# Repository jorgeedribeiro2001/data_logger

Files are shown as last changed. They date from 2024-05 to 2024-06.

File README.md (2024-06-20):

# Data Logger Project

## Overview
This repository contains the implementation of a data logger project designed for real-time and remote data acquisition during the shipment of products. The project includes scripts for data processing, device software, and a web interface for data visualization and control.

## Repository Structure

- **Back-End Scripts**: Scripts for data processing and storage.
- **Device Software (Microcontroller)**: Code for the microcontroller used in the data logging device.
- **Django Web-Framework**: Web application framework for interfacing with the data logger.
- **Tests and Results**: Testing scripts and result logs.
- **PCB Project**: KiCad Project of the PCB for the prototype.

## Description of the Implemented Solution

The data logger system uses the ESP32-E Firebeetle 2 microcontroller as the main unit. It works with several sensors to meet the project's requirements:

- **Vibration and Impact Monitoring**: Uses the IAM-20680 accelerometer and gyroscope.
- **Environmental Monitoring**: Uses the BME680 sensor to measure temperature, humidity, and pressure. Both sensors communicate with the microcontroller using the I2C protocol.
- **Data Storage**: Uses a PMod microSD reader module, which communicates via the SPI protocol, for local data storage.
- **Mobile Communication and GPS**: Uses the Ai-Thinker A9G module for mobile network communication and GPS tracking, interfacing via the UART protocol.

Data is sent using the MQTT protocol. Back-end scripts receive this data, convert it to JSON format, and send it to the Django web framework using HTTP Post requests.

##### Django Web Platform

The Django framework manages the data and web platform, providing features such as:

- **Data Storage**: Uses an SQLite database to store user information, trip details, configurations, and data file paths.
- **Interactive Visualization**: Uses JavaScript libraries like Highcharts for graphs and Leaflet for maps to show dynamic data on the trip monitoring page.

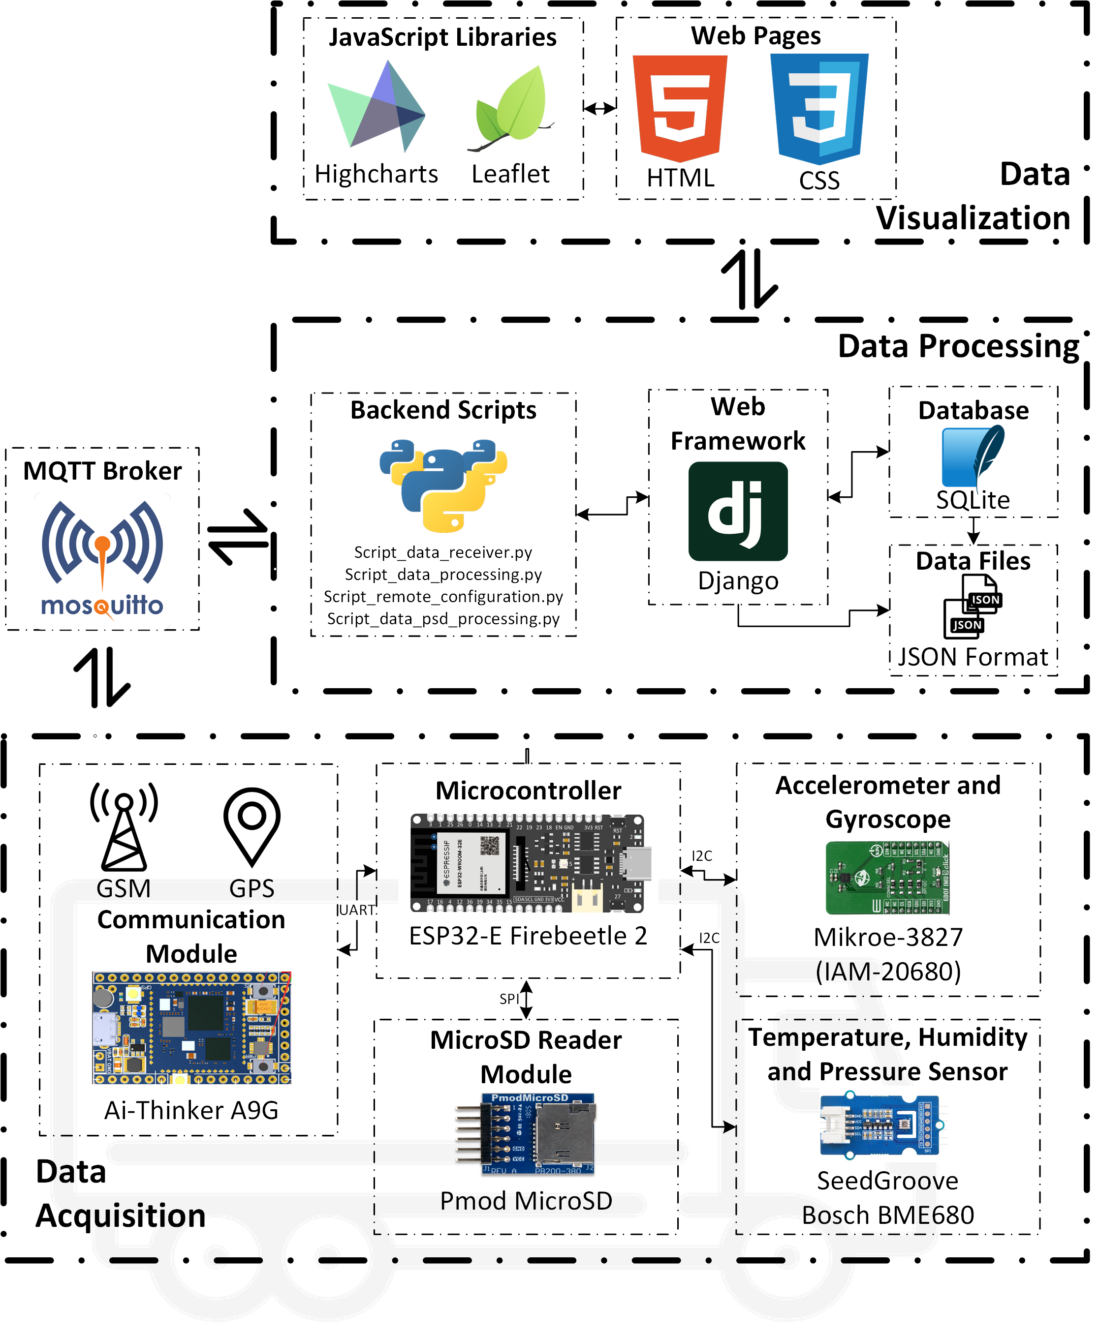
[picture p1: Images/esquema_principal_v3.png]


## Data Acquisition
A prototype was made with a PCB (KiCad Project), as shown in the next picture. This solution has one I2C connector with a Groove connector for the BME680 sensor. Two more I2C connectors are used, each with a TE Connectivity 1744418-4 connector with a 2.5mm pitch. Two SPI connectors have been added. One is for the microSD module, while the other is for the CS pin linked to GPIO 35 (A3) of the ESP32. The latter connector uses the TE Connectivity 1744418-6 with a 2.5mm pitch. This lets you add or try out other sensors. The design also has extra pins for GND, 3V3, and VCC, as well as two ESP32 serial port pins and extra free GPIOs, all marked on the PCB.

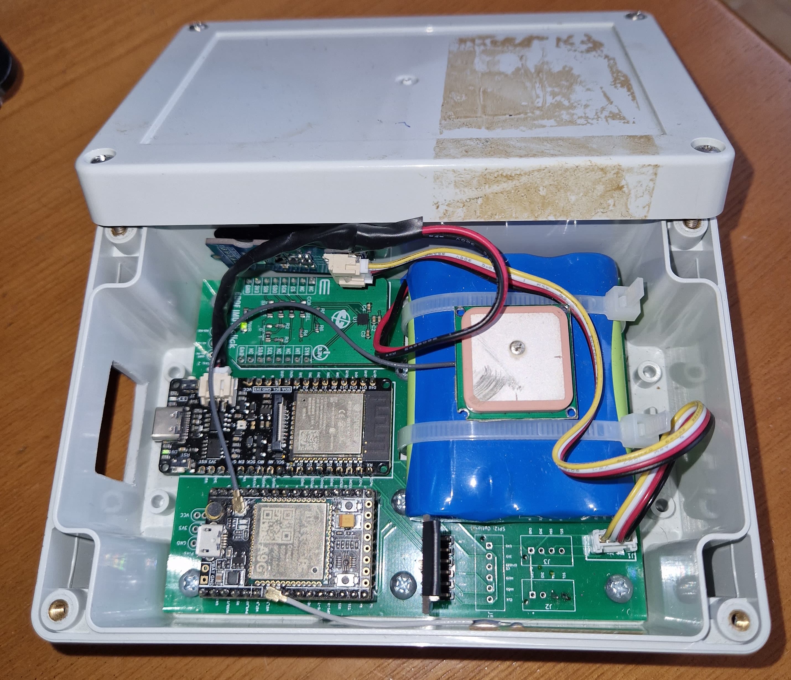
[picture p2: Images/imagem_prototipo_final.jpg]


### Microcontroller Program

The microcontroller program is developed using the ESP32 microcontroller and various sensors to monitor parameters such as temperature, humidity, pressure, impacts, vibration, and location. The code is structured into tasks that handle sensor readings, data storage, and communication with the web platform via MQTT.

### Key Components:
- **ESP32 Microcontroller**: Handles sensor integration and data processing.
- **Sensors**: Include BME680 for environmental data, IMU for motion data, and the Ai-Thinker A9G for location tracking and communication.
- **SD Card**: Certain SD cards are occasionally unrecognised by the device. To ascertain the functionality of an SD card, connect the device to a computer and open a serial port. During the initialisation process, the system will indicate whether the SD card is recognisable. If the card is recognised, the available memory will be displayed. ***It is crucial to format the SD card using the FAT32 file system to ensure proper operation.*** Among the tested SD cards, the Kingston CANVAS Select Plus models with capacities of 32GB and 64GB (class 10) have proven to be reliable.

- **SIM Card**: The device is configured to utilise a SIM plan card for communication via a 2G network to access the internet. The SIM operator employed in this instance is Vodafone Portugal, with the Access Point Name (APN) specified as `net2.vodafone.pt`.
   
   ***It is crucial to note that if a different SIM operator is used, it is necessary to modify the APN configuration within the hardware programme to match the new operator's APN. Furthermore, it is imperative to disable the PIN on the SIM card, as the device lacks the capability to handle PIN entry.*** This functionality must be implemented to avoid potential security vulnerabilities.

### Running the Microcontroller Program:
1. **Set Up the Development Environment**:
   - Install the necessary tools and libraries for ESP32 development.
   - Use the Arduino IDE or PlatformIO for code uploading.

2. **Upload the Code**:
   - Connect the ESP32 to your computer.
   - Compile and upload the code from the `microcontroller` directory.

For initial configurations, the device is pre-configured with specific settings, such as a unique identifier, the initial MQTT address and port, and the APN for network connectivity. This can be encounter on the PogV8.ino file.

hardware_configs

If you do not wish to use the remote configuration feature, you can manually define each configuration below in the `Definitions of Global Variables of the Program` section. To do this, you will need to set the `remote_configuration` variable to `false`. 

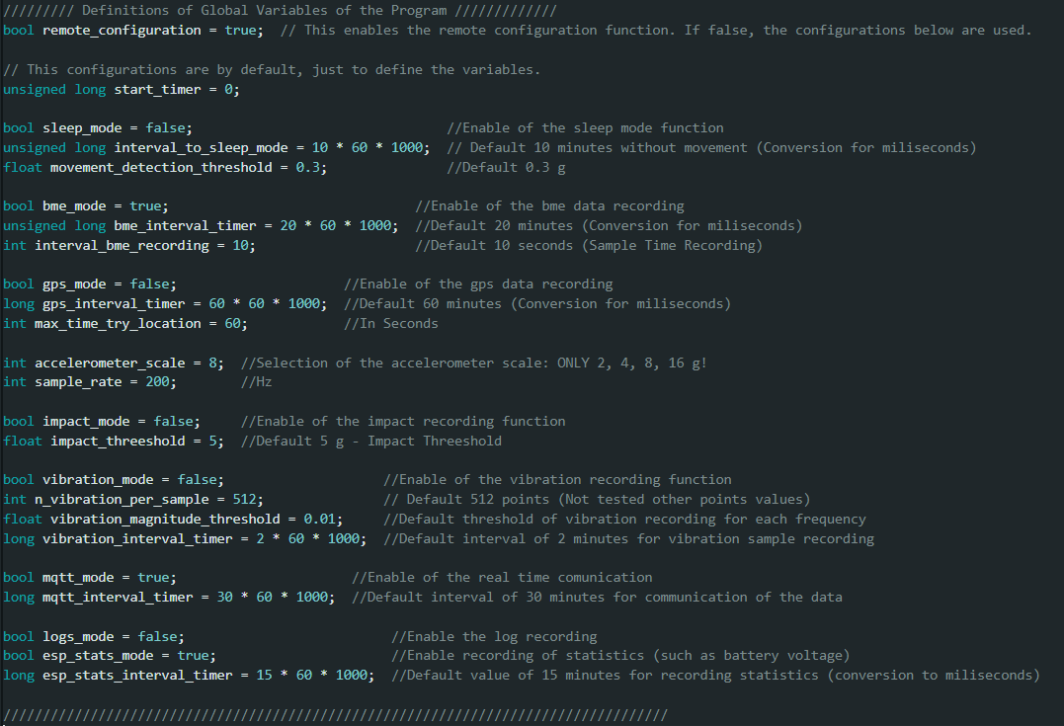
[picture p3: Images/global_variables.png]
hardware_configs2


In the case of remote configuration, if a configuration file is present, the system variables are set according to the specifications outlined in the JSON document created in the "Create Trip" webpage. If the internal memory does not contain a configuration file, the A9G module is activated and configured. This module subscribes to the "config" topic on the MQTT broker and awaits the receipt of the JSON file for up to 60 seconds. During this interval, the embedded LED on the microcontroller is programmed to blink at 500 ms intervals. The user must access the Devices Manager webpage and then press the button "Send Configuration."
Upon receipt of a file, the device proceeds to process it and verify whether the JSON file’s device ID matches the ID coded into the device. Each device ID is unique. If the IDs match, the device sets all global variables and copies the JSON file to the internal memory. Once the configuration is complete, the LED remains illuminated for three seconds before turning off. This signifies the setup process is finished and the system is ready for operation.

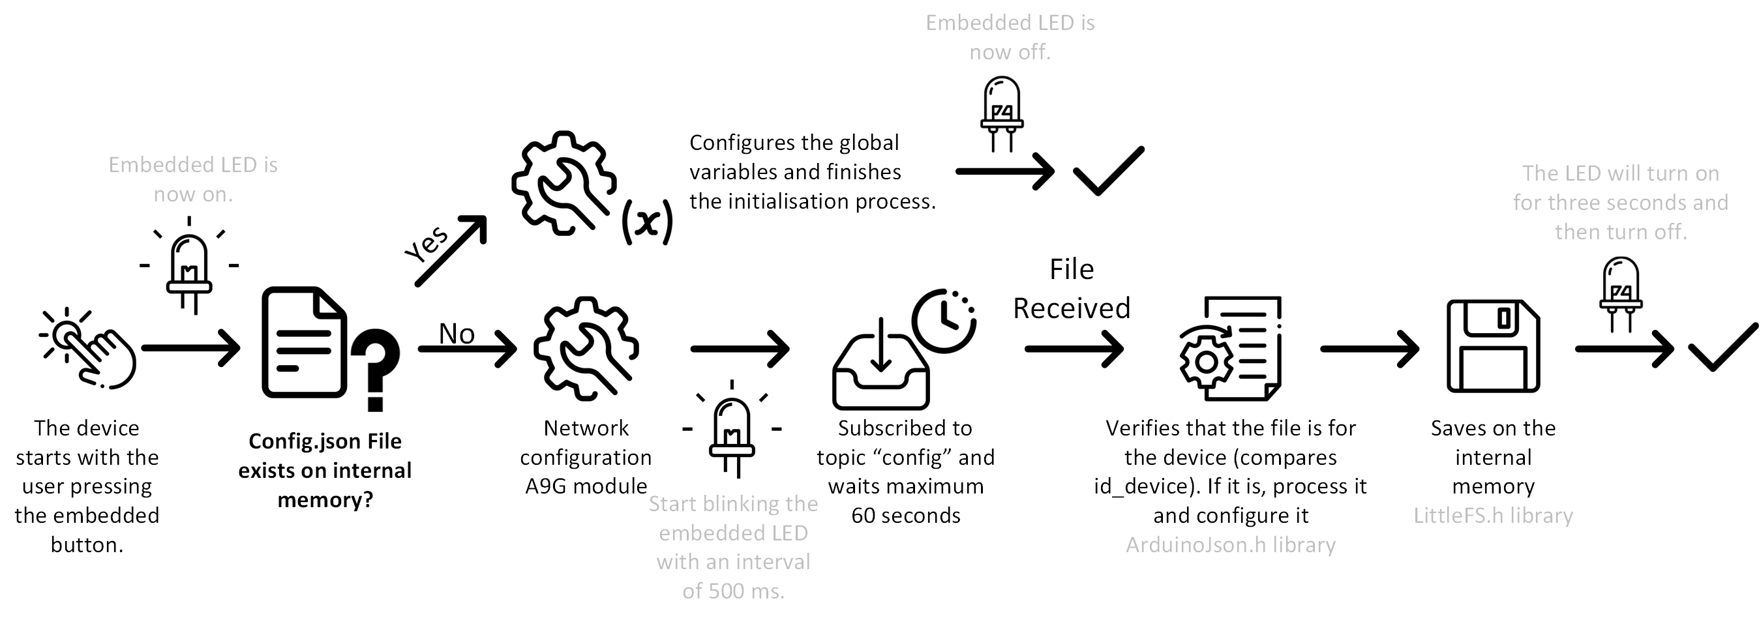
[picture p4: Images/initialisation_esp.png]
remote_config


The end mode, represented in Figure 4.13, is initiated when the user presses the embedded button on the microcontroller for a period of three seconds, thereby initiating the procedure and activating the embedded LED.

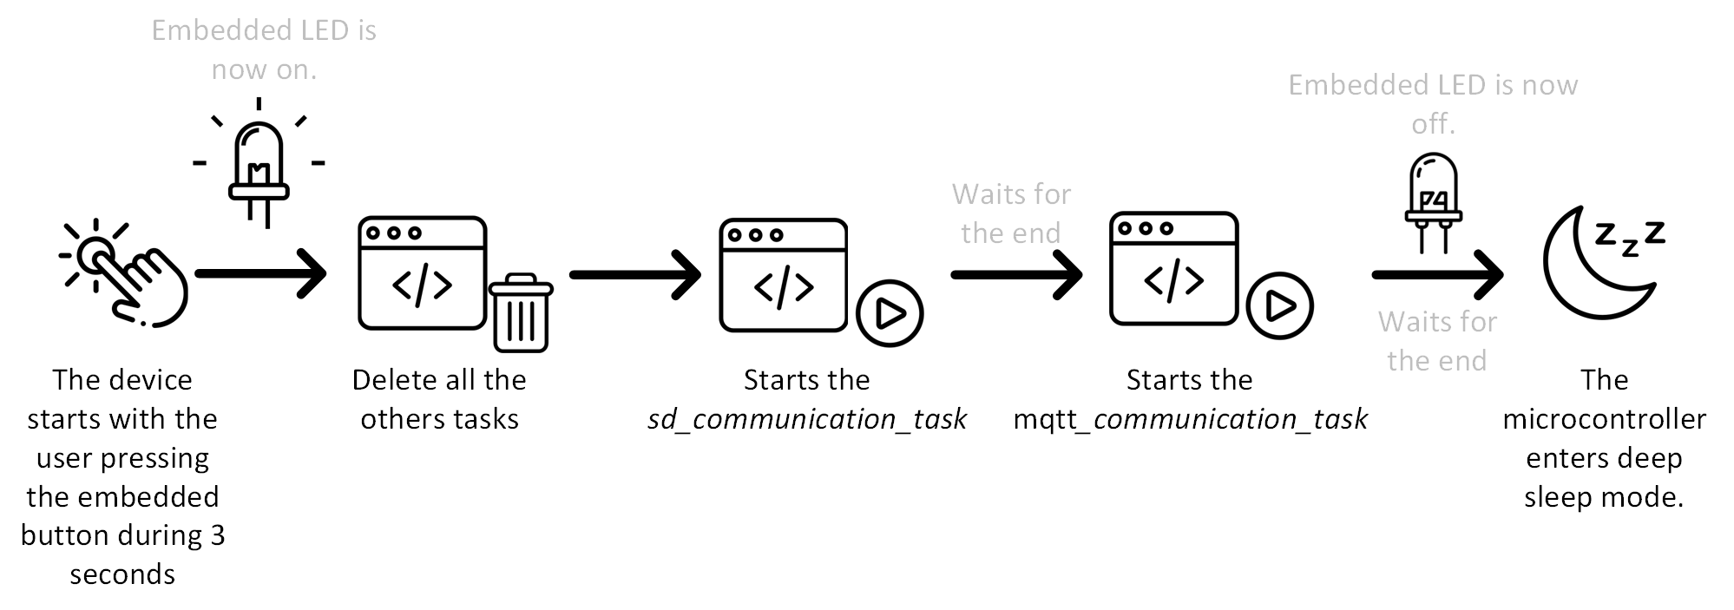
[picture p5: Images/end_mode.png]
end_mode


## Data Processing and Visualization

The data processing and visualization for the data logger system is managed through a series of scripts and a Django-based web platform. The system architecture and the functions of each script are described below.

### System Architecture

1. **Data Acquisition**:
   - The data logger devices collect data on temperature, humidity, pressure, impacts, vibration, and location.
   - This data is transmitted to the MQTT Broker (Mosquitto) using the MQTT protocol.

2. **Data Processing**:
   - **Script Data Receiver**: Subscribes to the MQTT topics to receive data from the data loggers.
   - **Script Data Processing**: Processes the raw data, converts it into JSON format, and prepares it for storage and visualization.
   - **Script Remote Configuration**: Publishes configuration settings to the data loggers.

3. **Data Storage and Management**:
   - The processed data is stored in an SQLite database, which keeps information about users, trips, trip configurations, and data file paths.
   - Additional processing by **Script Data PSD Processing** converts the raw data for FFT segments into Power Spectral Density (PSD) format for further analysis in the web platform.

4. **Web Framework (Django)**:
   - **Views.py**: Handles HTTP requests and returns responses to the client. It interacts with the models and templates to fetch and display data.
   - **Models.py**: Defines the database schema and interacts with the SQLite database to retrieve and store data.
   - **Urls.py**: Maps URLs to the corresponding views, enabling navigation within the web application.
   - **Templates**: HTML files that render the data into user-friendly web pages.

5. **Visualization**:
   - The web platform uses JavaScript libraries such as Highcharts and Leaflet for interactive data visualization.
   - **Highcharts**: Generates interactive graphs to display real-time and historical data on environmental conditions and impacts.
   - **Leaflet**: Provides map visualizations with recorded GPS points for tracking the location of shipments.

### Process Flow

- Data is continuously collected by the data loggers and transmitted via MQTT.
- The **Script Data Receiver** listens for incoming data and passes it to the **Script Data Processing**.
- Processed data is stored in the SQLite database and can be accessed through the Django web platform.
- Users can interact with the platform to configure devices, monitor ongoing trips, and visualize data through dynamic graphs and maps.

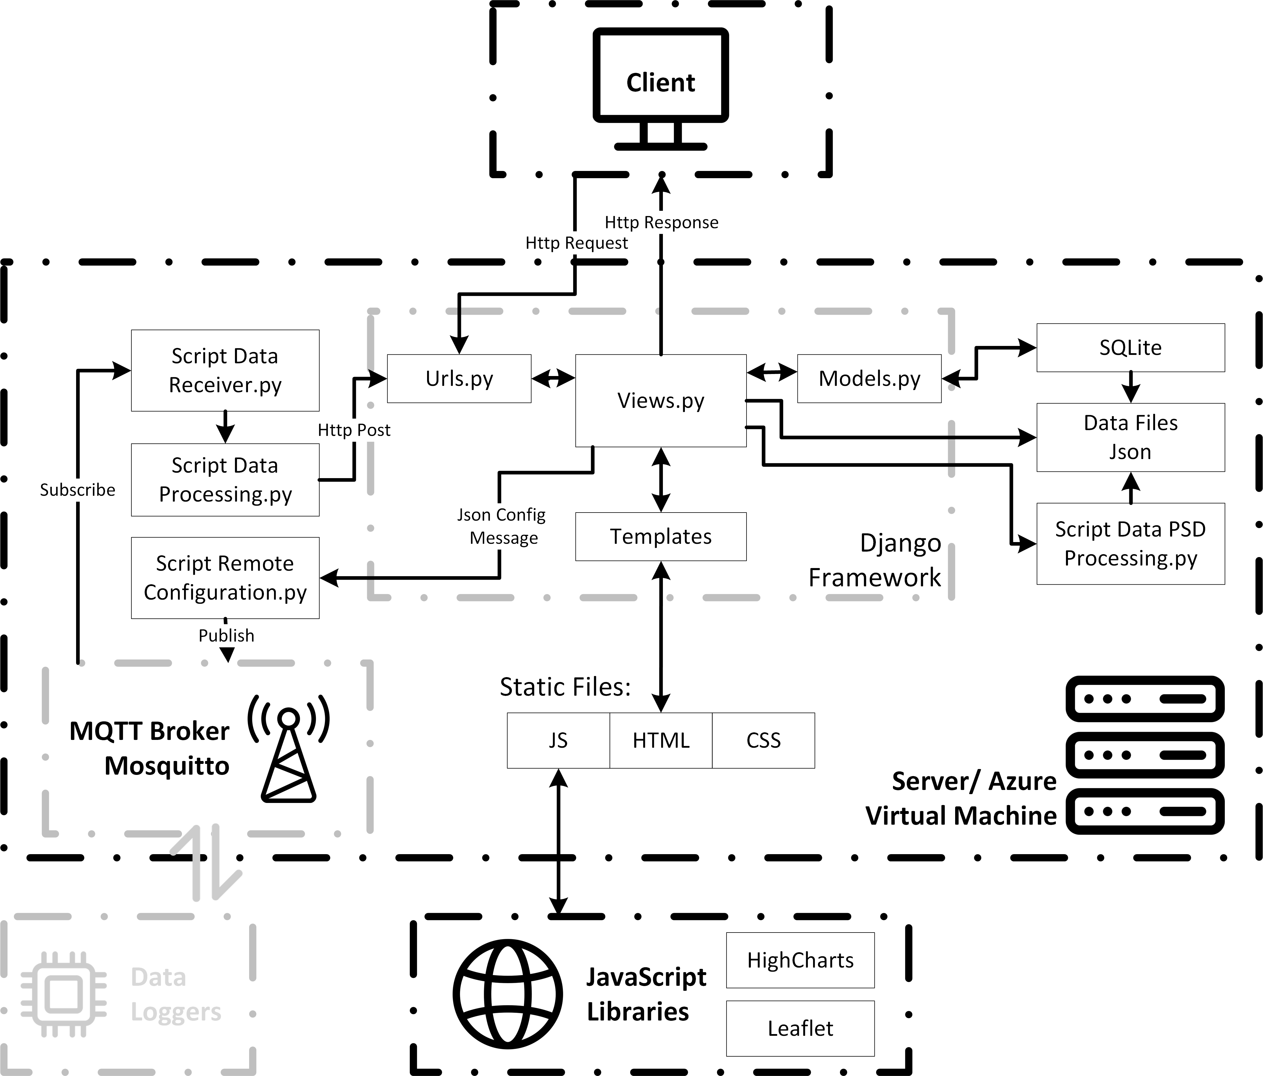
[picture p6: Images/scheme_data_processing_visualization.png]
Platform Diagram


### Running the Server

When setting up the server, three key considerations must be addressed:

- **MQTT Server Configuration**: Although it is possible to use an external MQTT server, such as broker.hivemq.com or broker.emqx.io, it is advisable to install and configure Eclipse Mosquitto on the server to ensure greater system reliability. ***Additionally, Port 1883 should be opened for public access***.

- **Script Data Receiver**: Ensure that the Script Data Receiver (Python Script) is running continuously. This script is designed to operate without interruption and includes error-handling mechanisms to facilitate automatic rebooting. ***It is important to configure the MQTT address and port at the beginning of the program.***

- **Django Web Framework Configuration**: Properly configure the Django web framework. Detailed instructions for configuring Django will be provided in the subsequent section.

#### Running the Django Web-Framework

1. **Clone the Repository**:
   ```bash
   git clone https://github.com/jorgeedribeiro2001/data_logger_project.git
   cd data_logger_project
   ```

2. **Install Dependencies**:
   - For Python components, use the requirements file:
     ```bash
     pip install -r requirements.txt
     ```

3. **Run the Django Application**:
   - Navigate to the Django project directory:
     ```bash
     cd django_project
     ```
   - Apply migrations:
     ```bash
     python manage.py migrate
     ```
   - Create a superuser to access the admin interface:
     ```bash
     python manage.py createsuperuser
     ```
   - Start the development server:
     ```bash
     python manage.py runserver
     ```
   - Access the application at `http://127.0.0.1:8000/`.

To run the Django application over the internet, ensure you have a public IP address and an available port.
It is notable that the platform was not developed for public porposes and not went with any security concerns. Follow these steps to run the application:

1. **Open the Server to External Access**:
   Run the Django development server with the following command to make it accessible over the internet:
   ```bash
   python manage.py runserver 0.0.0.0:8000
   ```

2. **Public IP and Port**:
   - Ensure your server's firewall allows traffic on the specified port (e.g., 8000).
   - Configure your router to forward incoming traffic on this port to your server if running behind a NAT.

3. **Security Considerations**:
   - This platform was developed for demonstration purposes and internal use only.
   - It lacks security features necessary for a public-facing application.
   - If you intend to make this application accessible over the internet, implement proper security measures such as HTTPS, firewalls, authentication, and regular security audits.

4. **Deployment Recommendations**:
   - For production deployment, use a robust web server like Nginx or Apache as a reverse proxy.
   - Consider using a WSGI server like Gunicorn or uWSGI to serve the Django application.
   - Set up SSL/TLS certificates for secure HTTPS connections.

### Graphical Interface

The graphical interface of the data logger system includes several user-accessible pages designed as adaptable templates. These templates ensure that the HTML pages dynamically respond to user requests. For instance, when a user monitors a trip, the page's structure and elements adjust automatically to display the specific trip data selected by the user. Below is a visual representation of the hierarchical structure of these pages:

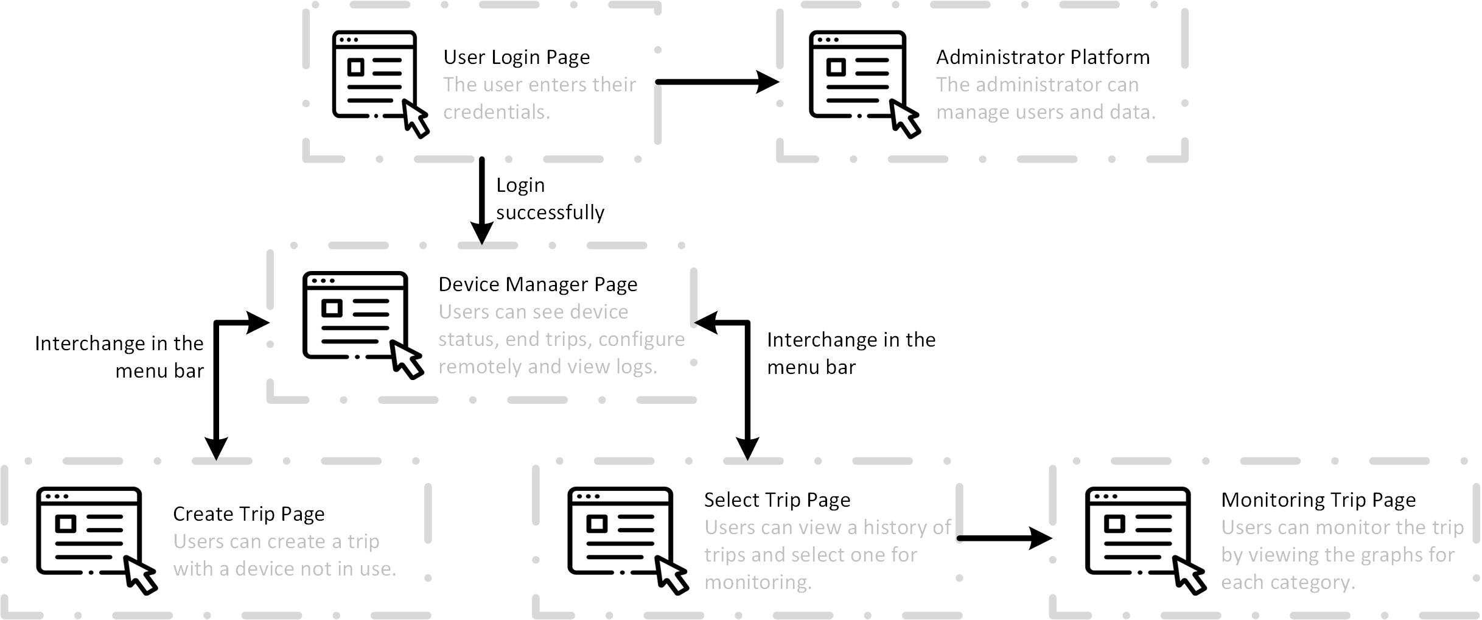
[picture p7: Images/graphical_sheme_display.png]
Web Pages Interaction Diagram

*Figure: Web Pages Interaction Diagram*

#### Page Descriptions

##### User Login Page
The user login page is the primary access point for users. It features a straightforward interface where users can enter their credentials. Upon successful login, users are redirected to the appropriate dashboard. Administrators can also access the administrative platform from this page.

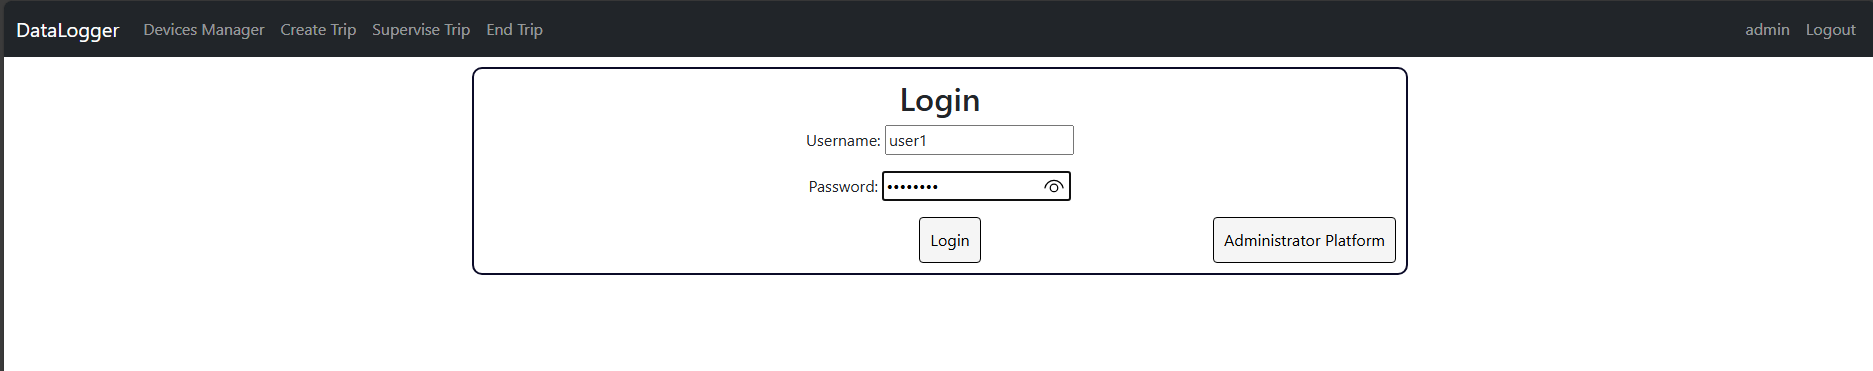
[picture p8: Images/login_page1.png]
User Login Layout

*Figure: User Login Layout*

##### Administrator Platform
This platform is accessible only to administrators. It provides comprehensive data access and user management capabilities, allowing administrators to manage users, modify values in the SQLite database, and oversee data collected by the devices.

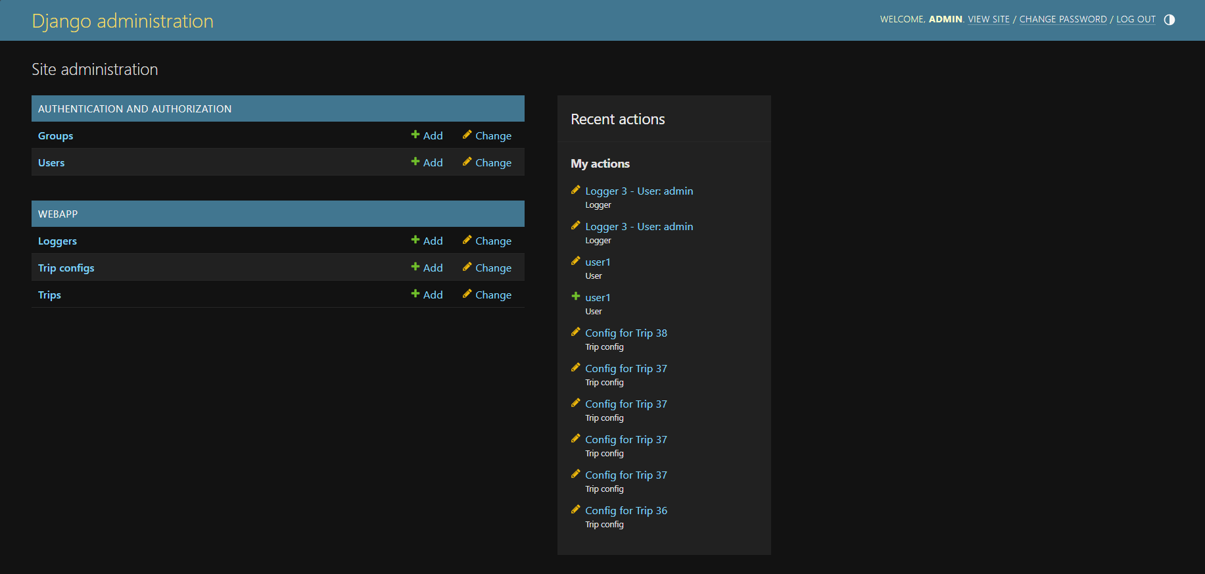
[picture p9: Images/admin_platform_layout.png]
Administrator Platform Layout

*Figure: Administrator Platform Layout*

##### Device Manager Page
Upon logging in, users are redirected to the Device Manager page. This page can also be accessed via the menu bar. It requires user authentication and displays the devices added by the user. Administrators can view all devices. Users can see device status, end trips, configure devices remotely, and view logs.

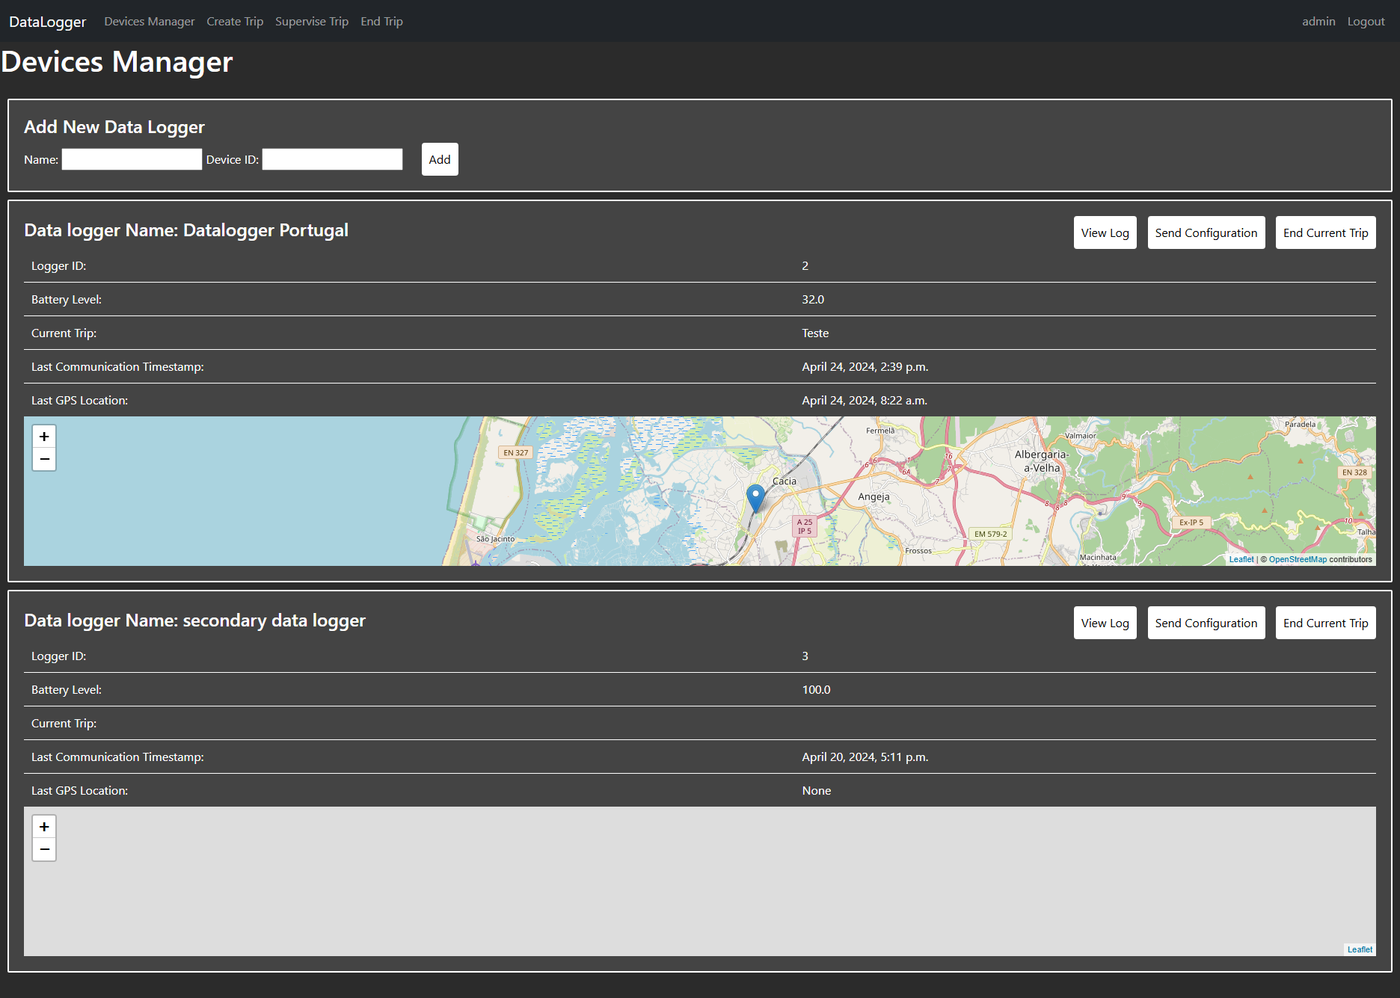
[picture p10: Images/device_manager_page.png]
Device Manager Page Layout

*Figure: Device Manager Page Layout*

##### Create Trip Page
This page allows users to create a new trip and configure the associated device settings. Users can navigate to this page via the menu bar or through a specific link. They can define the trip name, select an available data logger, and set the start date. Configuration parameters can be set, and a JSON file can be generated for saving on the user's computer.

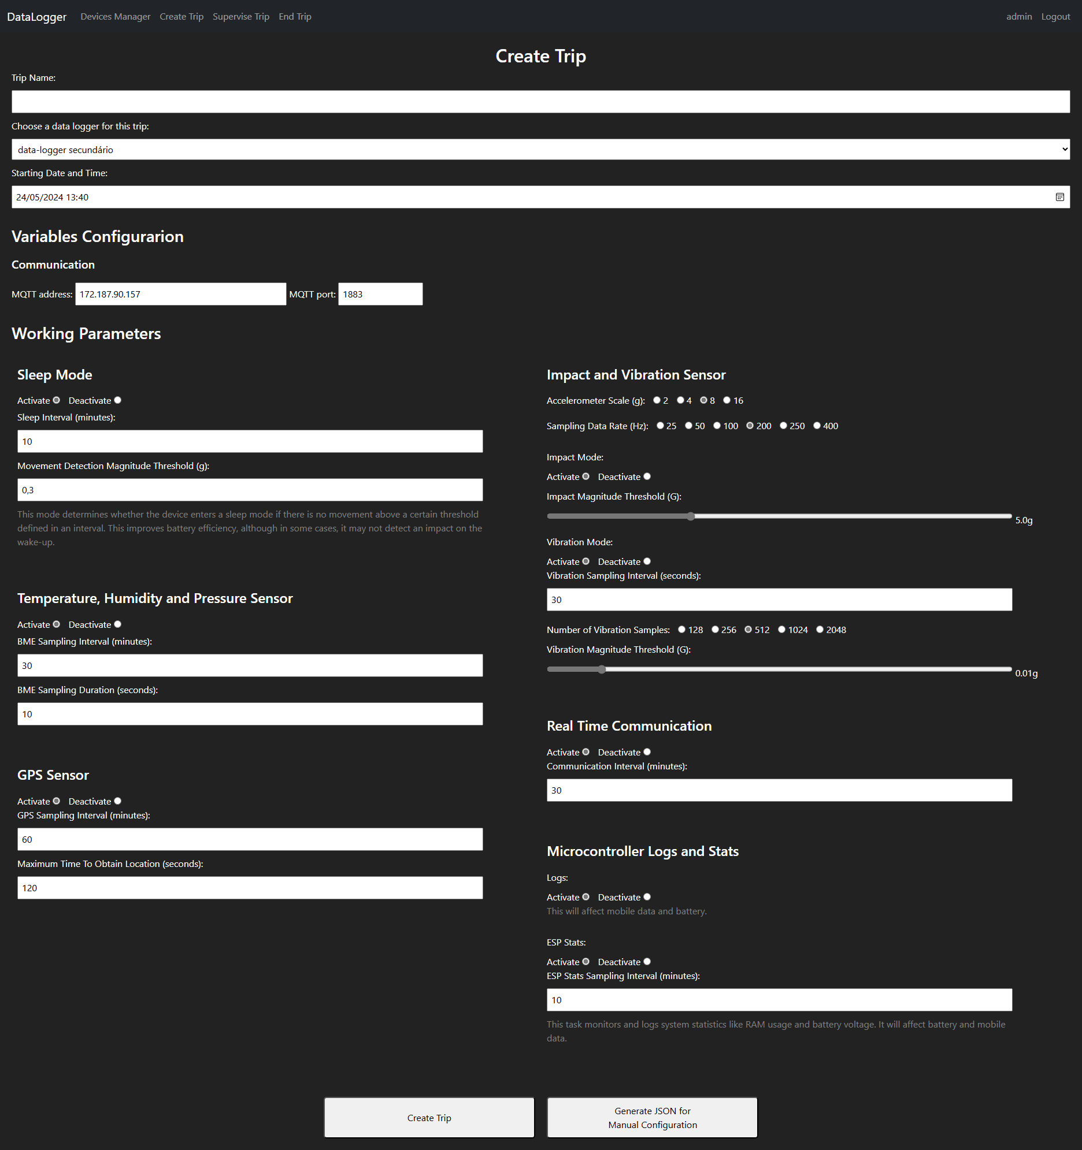
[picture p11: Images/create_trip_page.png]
Create Trip Page Layout

*Figure: Create Trip Page Layout*

##### Select Trip Page
The Select Trip page allows users to view and select from a list of their trips. Users can delete a trip or proceed to monitor it. This page is accessible via the menu bar and requires user authentication.

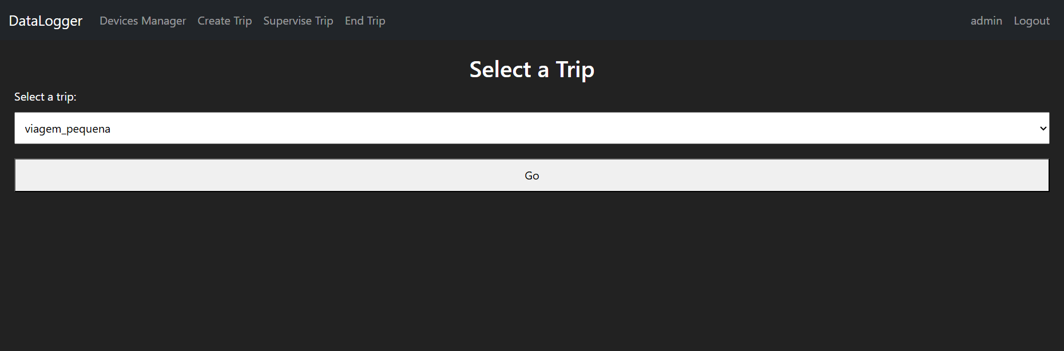
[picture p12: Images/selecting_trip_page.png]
Select Trip Page Layout

*Figure: Select Trip Page Layout*

##### Monitoring Trip Page
This page is crucial for data analysis and visualization. It is divided into sections for general trip details, BME data (temperature, humidity, pressure), IMU data (impact, vibration), and location data. Each section provides detailed analysis and interactive graphs.

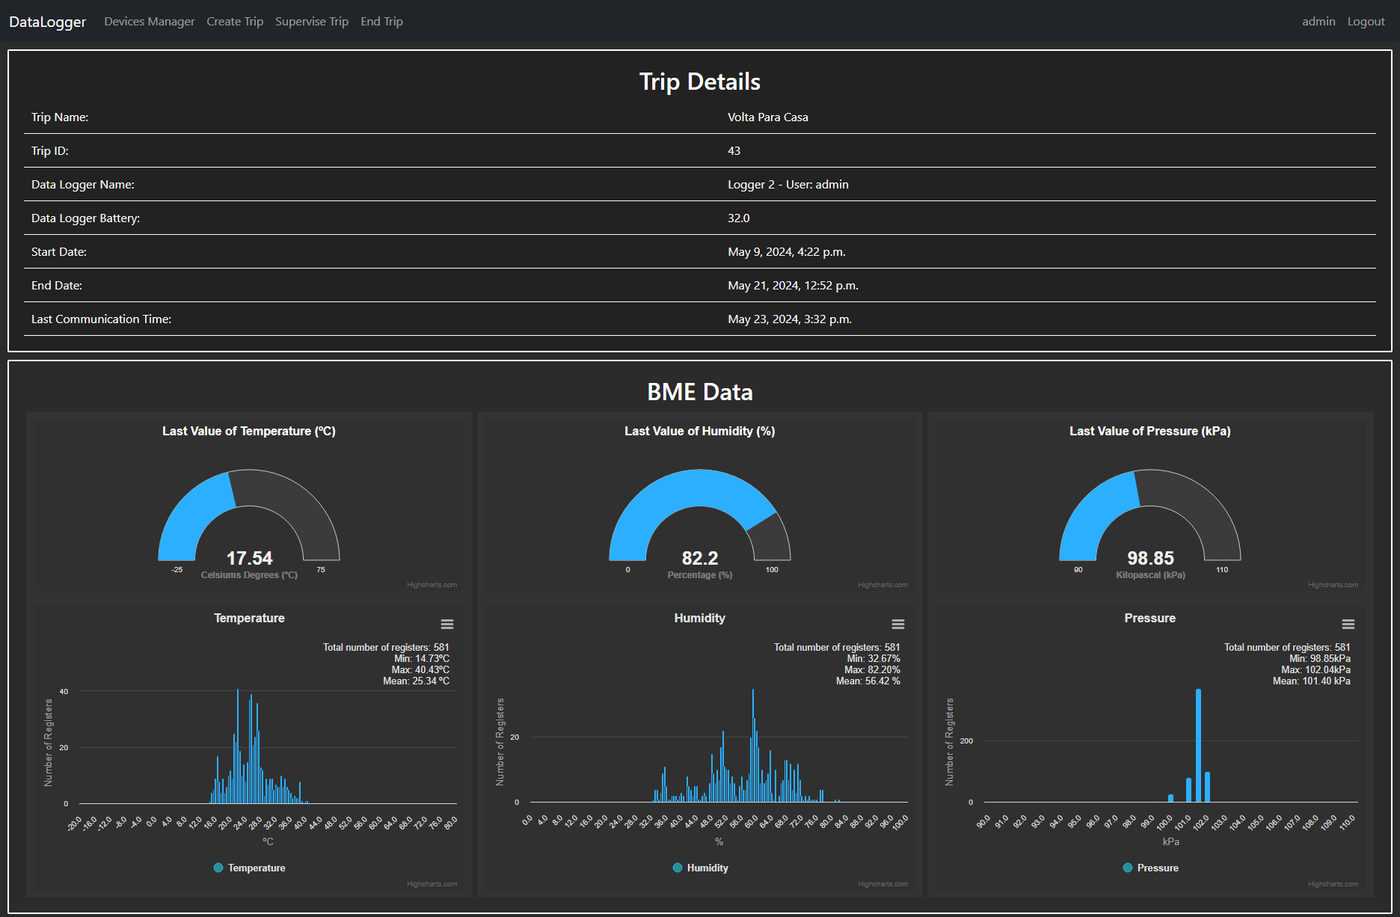
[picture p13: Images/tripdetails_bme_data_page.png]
Monitoring Page: Trip Details and BME Data Sections Layout

*Figure: Monitoring Page: Trip Details and BME Data Sections Layout*

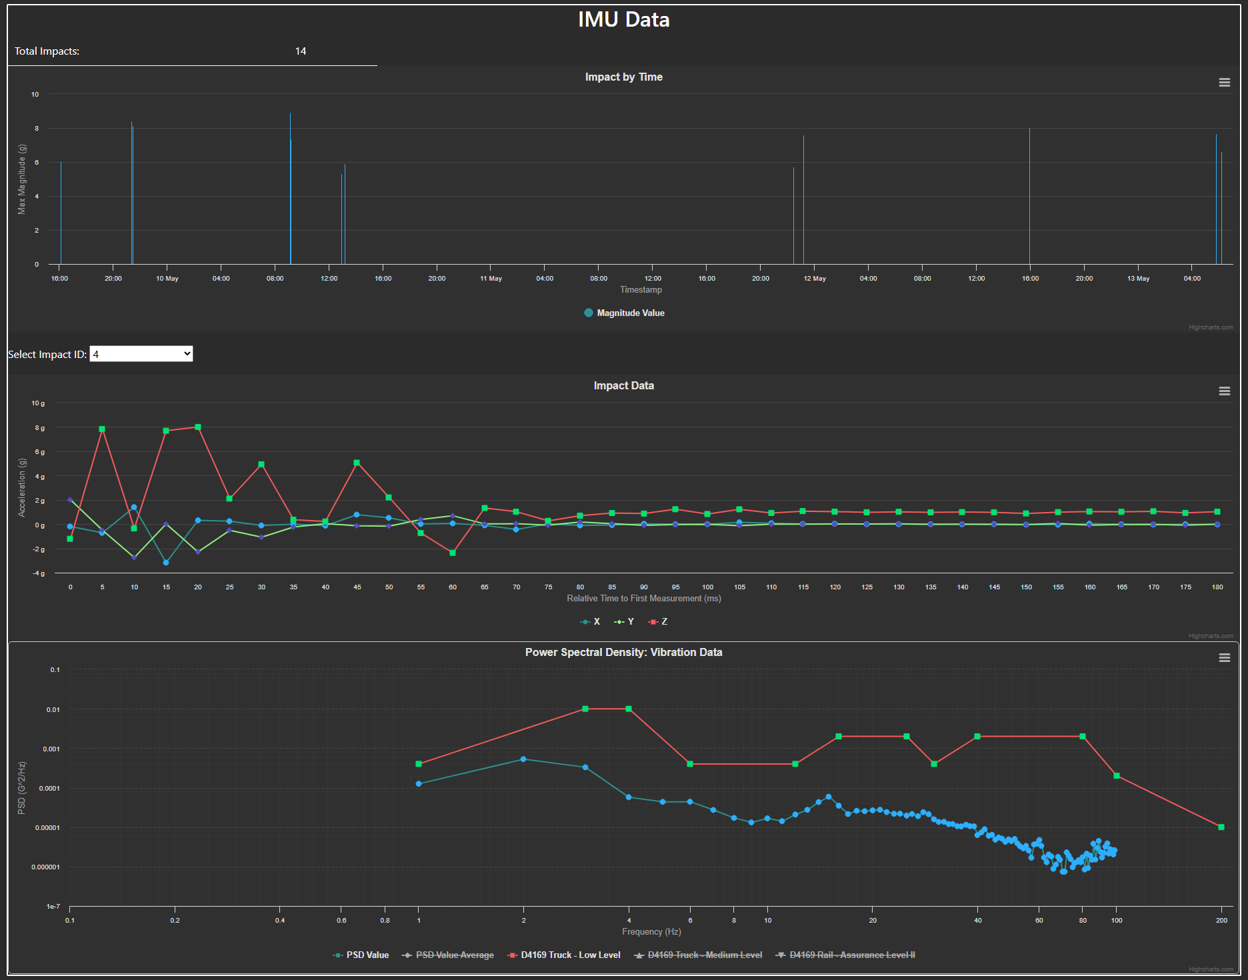
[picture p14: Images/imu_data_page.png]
Monitoring Page: IMU Data Section Layout

*Figure: Monitoring Page: IMU Data Section Layout*

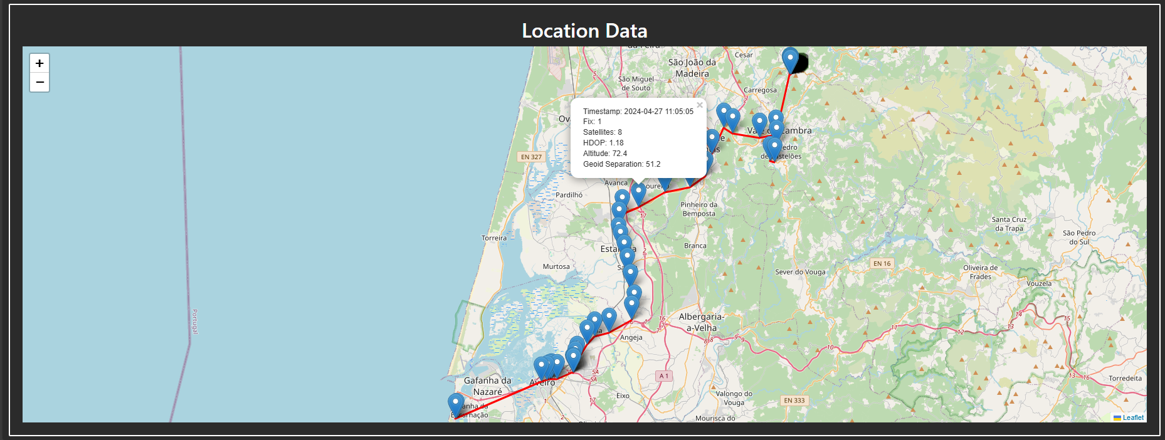
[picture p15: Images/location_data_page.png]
Monitoring Page: Location Section Layout

*Figure: Monitoring Page: Location Section Layout*

#### JavaScript Libraries
The interactive graphs and maps are created using the Highcharts and Leaflet JavaScript libraries. Highcharts is used for generating interactive graphs, while Leaflet is used for creating interactive maps with recorded position points. These tools provide dynamic visualization of the data collected by the data logger devices.

This graphical interface ensures a user-friendly and efficient way to manage devices, create and monitor trips, and visualize data for analysis, making it a vital part of the data logger system.

## Troubleshooting

##### When I turn on the device, the light is always on indefinitely.

This issue may arise due to initialization errors, often related to inaccessible sensors or the communication module's inability to connect to the network for remote configuration or microSD incompatibility. To troubleshoot, follow these steps:

- Verify that all sensor connections are secure.
- Ensure a compatible microSD card is in place.
- Confirm that the SIM card is functioning correctly.
- Check that the MQTT settings are properly configured.
  
To determine the specific cause, connect the device to a computer, open a serial port, and restart the device. This will display initialization information on the serial port. The baud rate should be set to 115200 bps.

##### The remote configuration does not work (the light keeps blinking after I click the Send Configuration button on the web platform).

This issue may be attributed to improper configuration of the MQTT server settings. Ensure that the device is configured with the correct MQTT broker address and port. Additionally, verify that the appropriate settings have been entered on the Create Trip webpage.

##### Despite the device being deployed in the field, the web platform is not receiving or displaying updated data.

Verify if the script data receiver is running with the correct MQTT configurations. Additionally, check if the issue is isolated to a single device or affects multiple devices. Examine the last communication timestamp of the device and ensure that the trip configurations have the communication interval set correctly. If all these aspects are in order, contact the repository owner for further assistance. Remember that the device communication might be skipped during the programmed interval but will resume in the subsequent interval.

## License
This project is licensed under the GNU General Public License v3.0.

## Contact
For any queries, contact the repository owner on LinkedIn page: https://www.linkedin.com/in/jorgeedribeiro/ 

---

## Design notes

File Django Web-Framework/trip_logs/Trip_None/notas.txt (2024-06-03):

DHl, rastreablilidade, transportadoras teses relacionadas 

dano no produto 

Henrique apresentação efacec 18 segunda 16h15

Transformada de Forier

rever 10 a 20 artigos e fazer uma pagina de resumo (analise do problema, soluçao proposta, metodo de analise de resultados, conclusoes) tiirar partes fundamentais para o projeto (sumo)

algoritmo de processamento de dados para vibrações (procurar artigos cientificos)

jason 

17:10 06/12/2023
artigos para verificar a antena de gps e erro de posição
dois cores processadores 
spyes dual cores, core posso ter varios processos
guardar na ram array[0] a [10] tem x valores de gps outros tem outra cena
processos independentes  
de ram

array[] com os parametros 
fluxograma de comandos AT

relação entre tempo e frequencia de vibração
um mes de performance em quanto nos testes
histograma de frequencia
retirar frequencia amostragem durante x tempo

francisco
teste de queue

try catch for log

te connectivity
174417-4 2.5mm

meter modulo de cartao sd
substituir por conector o mesmo com 6 pinos
tdl100 e 140 fazer comparação

SAVER 3X90

Apos acordar tem de registar algum valor a dozer que sofreu impacto ou que

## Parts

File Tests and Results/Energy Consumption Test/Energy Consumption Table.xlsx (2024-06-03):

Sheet: Individual Tests
Individual Tests
Sensor |  |  | Bosch BME680 |  | IAM-20680 | A9G |  |  |  | MicroSD |  | ESP32
Test |  |  | Data Recording Cycle | Sleeping Mode | Continuous monitoring of accelerometer values | Module Initialization (Reseting) | GPS Data Recording | MQTT data transmission | Sleep Mode | Data Writting | Sleep Mode | Tasks Manager Running | Sleep Mode
Test Description |  |  | A cycle that simulates the normal data recording procedure: switch on, record for 10 seconds (temperature, humidity and pressure) and then switch to the low power mode. | Consumption during 2 minutes | Consumption during 2 minutes | Start from normal mode and perform a reset to wake up the module and to configure it. | A cycle that simulates the normal data acquisition procedure: Switch on the GPS, wait for a maximum of 60 seconds to fix the satellite and, if successful, store the coordinates and then switch off the GPS. | Initial configuration of the network and then transfer of data from the microSD card | Consumption during a standby period | A cycle that simulates the process of transferring data from the RAM to the MicroSD. | Consumption during a standby period | Consumption measured on the microcontroller only when it is running on normal mode | Consumption measured on the microcontroller only when it is running on sleeping mode
Parameters |  |  | Mode: Forced Mode Over-Sampling 8x | Mode: Sleep-Mode | ODR 250 Hz Over-Sampling 8x | AT Command (AT+RST=1) | 60 Seconds Maximum Time to obtain Location | 1 minute duration. 15 setences per message. | 1 minute duration. | Testing using the Kingston SDCS2/32GB MicroSD Data Writting of 3 registers of Impacts Data and 5 registers of BME Data SPI frequency : 1MHz | 1 minute duration. | CPU Frequency: 160 MHz | CPU Frequency: 160 MHz
Results (1st Test) | Average Bus Voltage (V) |  | 3.25 | 3.26 | 3.24 | 4.80 | 4.77 | 4.71 | 4.81 | 3.30 | 3.26 | 3.90 | 3.92
 | Current Consumption (mA) | Min. Value | -0.01 | 0.00 | 5.30 | 11.00 | 12.50 | 13.40 | 2.00 | 0.40 | 0.30 | 31.90 | 1.50
 |  | Max. Value | 14.00 | 0.80 | 6.70 | 400.00 | 126.70 | 400.00 | 83.60 | 62.90 | 0.40 | 58.30 | 1.70
 |  | Avg. Value | 2.60 | 0.43 | 5.64 | 39.45 | 52.82 | 128.41 | 4.00 | 18.72 | 0.33 | 48.45 | 1.60
 | Shunt Voltage (mV) | Min. Value | -0.01 | 0.00 | 0.53 | 1.09 | 1.25 | 1.34 | 0.20 | 0.05 | 0.02 | 3.31 | 0.15
 |  | Max. Value | 1.63 | 0.04 | 0.63 | 40.00 | 12.52 | 40.00 | 80.90 | 5.82 | 0.04 | 5.77 | 0.17
 |  | Avg. Value | 0.23 | 0.00 | 0.56 | 4.46 | 5.29 | 12.32 | 0.40 | 1.80 | 0.03 | 4.86 | 0.16
 | Power Consumption (mW) | Min. Value | 0.00 | 0.00 | 18.00 | 52.00 | 61.00 | 64.00 | 10.00 | 2.00 | 2.00 | 128.00 | 7.00
 |  | Max. Value | 46.00 | 2.00 | 21.00 | 1924.00 | 596.00 | 1927.00 | 403.00 | 200.00 | 2.00 | 228.00 | 7.00
 |  | Avg. Value | 8.44 | 1.38 | 18.36 | 177.91 | 251.15 | 587.63 | 19.15 | 59.32 | 2.00 | 186.33 | 7.00
 | Total Energy Con. (mWh) |  | 0.037980 | 0.023110 | 0.613525 | 1.008170 | 4.590470 | 9.826440 | 0.320690 | 0.535530 | 0.033500 | 3.159830 | 0.117440
Results (2st Test) | Average Bus Voltage (V) |  | 3.25 | - | 3.24 | 4.79 | 4.77 | 4.66 | 4.80 | 3.27 | 3.26 | 3.90 | -
 | Current Consumption (mA) | Min. Value | -0.10 | - | 5.30 | 11.10 | 12.60 | 63.80 | 2.00 | 0.50 | 0.20 | 32.50 | -
 |  | Max. Value | 14.80 | - | 6.50 | 400.00 | 118.10 | 400.00 | 75.20 | 63.40 | 0.40 | 55.50 | -
 |  | Avg. Value | 1.87 | - | 5.60 | 37.66 | 48.42 | 170.66 | 4.22 | 18.55 | 0.31 | 48.33 | -
 | Shunt Voltage (mV) | Min. Value | -0.01 | - | 0.54 | 1.11 | 1.26 | 6.48 | 0.20 | 0.04 | 0.02 | 3.23 | -
 |  | Max. Value | 1.66 | - | 0.64 | 40.00 | 11.84 | 40.00 | 7.60 | 6.34 | 0.04 | 5.55 | -
 |  | Avg. Value | 0.20 | - | 0.56 | 4.19 | 4.84 | 16.56 | 0.44 | 1.77 | 0.03 | 4.86 | -
 | Power Consumption (mW) | Min. Value | 0.00 | - | 16.00 | 52.00 | 61.00 | 305.00 | 10.00 | 2.00 | 0.00 | 128.00 | -
 |  | Max. Value | 39.00 | - | 21.00 | 1458.00 | 557.00 | 1912.00 | 398.00 | 185.00 | 2.00 | 216.00 | -
 |  | Avg. Value | 6.03 | - | 18.21 | 165.53 | 231.49 | 794.36 | 20.21 | 60.31 | 2.00 | 186.06 | -
 | Total Energy (mWh) |  | 0.028310 | - | 0.608012 | 0.942610 | 4.192530 | 13.305390 | 0.337970 | 0.604810 | 0.033390 | 3.121690 | -
Results (3st Test) | Average Bus Voltage (V) |  | 3.25 | - | 3.24 | 4.80 | 4.77 | 4.67 | 4.80 | 3.28 | 3.26 | 3.90 | -
 | Current Consumption (mA) | Min. Value | -0.10 | - | 5.30 | 10.90 | 12.50 | 61.20 | 2.00 | 0.30 | 0.20 | 38.00 | -
 |  | Max. Value | 15.70 | - | 6.60 | 400.00 | 115.20 | 400.00 | 81.10 | 63.10 | 0.40 | 55.90 | -
 |  | Avg. Value | 2.45 | - | 5.60 | 42.66 | 48.11 | 167.75 | 3.77 | 17.13 | 0.32 | 48.90 | -
 | Shunt Voltage (mV) | Min. Value | -0.01 | - | 0.54 | 1.09 | 1.25 | 6.13 | 0.20 | 0.04 | 0.02 | 3.31 | -
 |  | Max. Value | 1.21 | - | 0.65 | 40.00 | 11.49 | 40.00 | 8.11 | 4.91 | 0.04 | 5.58 | -
 |  | Avg. Value | 0.22 | - | 0.55 | 4.46 | 4.81 | 16.48 | 0.36 | 1.72 | 0.03 | 4.93 | -
 | Power Consumption (mW) | Min. Value | 0.00 | - | 18.00 | 52.00 | 61.00 | 285.00 | 10.00 | 2.00 | 0.00 | 129.00 | -
 |  | Max. Value | 51.00 | - | 21.00 | 1892.00 | 542.00 | 1914.00 | 382.00 | 200.00 | 2.00 | 218.00 | -
 |  | Avg. Value | 8.29 | - | 18.48 | 176.06 | 228.99 | 780.09 | 16.81 | 55.93 | 1.99 | 190.14 | -
 | Total Energy (mWh) |  | 0.030860 | - | 0.617540 | 0.953620 | 4.115390 | 13.044670 | 0.281060 | 0.501830 | 0.033280 | 3.184830 | -

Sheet: Use Case
Use Case
Start Point
Type | Time | Decimal |  | Total Time | Percentage
Transport | 5h10m | 5.17 | Theorical Transport: | 78.94 | 88.09%
Storage | 0h00m | 0 | Taking into account a rest period of 9 hours in a 24-hour period of transport
Transport | 20h51m | 20.85
Storage | 0h04m | 0.07 | Resting: | 29.60 | 33.03%
Transport | 34h42m | 37.7 | Storage: | 10.67 | 11.91%
Storage | 10h36m | 10.6 | Real Transport: | 49.34 | 55.06%
Transport | 15h13m | 15.22
End Point
Total: |  | 89.61

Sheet: Consumption per Mode and Hour
Estimated Power Consumption
Action/component | Mode | Active Mode (Real Transport) | Sleeping Mode (Storage + Resting)
 | Mode Usage Percentage: | 55% | 45%
bme | nº cycles | 2 | 1
 | Usage Time per cycle (minutes) | 0.17 | 0.17
 | Percentage Usage (%) | 0.56% | 0.28%
 | Active Power Consumption (mW) | 7.587 | 7.587
 | Sleep Power Consumption (mW) | 1.380 | 1.380
 | Total Energy per hour (mWh) | 1.414 | 1.397
imu | nº cycles | 1 | 1
 | Usage Time per cycle (minutes) | 60.00 | 60.00
 | Percentage Usage (%) | 100.00% | 100.00%
 | Active Power Consumption (mW) | 18.350 | 18.350
 | Sleep Power Consumption (mW) | 0.000 | 0.000
 | Total Energy per hour (mWh) | 18.350 | 18.350
A9G | Module Inicialization
 | nº cycles | 1 | 0
 | Usage Time per cycle (minutes) | 0.33 | 0.33
 | Percentage Usage (%) | 0.56% | 0.00%
 | Active Power Consumption (mW) | 173.167 | 173.167
 | Total Energy per hour (mWh) | 0.962 | 0.000
 | GPS
 | nº cycles | 1 | 0
 | Usage Time per cycle (minutes) | 1.00 | 1.00
 | Percentage Usage (%) | 1.67% | 0.00%
 | Active Power Consumption (mW) | 237.210 | 237.210
 | Total Energy per hour (mWh) | 3.954 | 0.000
 | Data Transmission
 | nº cycles | 1 | 0
 | Usage Time per cycle (minutes) | 5.00 | 5.00
 | Percentage Usage (%) | 8.33% | 0.00%
 | Active Power Consumption (mW) | 720.693 | 720.693
 | Total Energy per hour (mWh) | 60.058 | 0.000
 | Module
 | Usage Time (minutes) | 53.67 | 60.00
 | Percentage Usage (%) | 89.44% | 100.00%
 | Sleep Power Consumption (mWh) | 18.723 | 18.723
 | Total Energy per hour (mWh) | 16.747 | 18.723
Micro-SD | nº cycles | 5 | 1
 | Usage Time per cycle (minutes) | 2.00 | 2.00
 | Percentage Usage (%) | 16.67% | 3.33%
 | Active Power Consumption (mW) | 58.520 | 58.520
 | Sleep Power Consumption (mW) | 1.997 | 1.997
 | Total Energy per hour (mWh) | 11.417 | 3.881
Microcontroller | nº cycles | 1 | 2
 | Usage Time per cycle (minutes) | 60.00 | 5.00
 | Percentage Usage (%) | 100.00% | 16.67%
 | Active Power Consumption (mW) | 187.510 | 187.510
 | Sleep Power Consumption (mW) | 7.000 | 7.000
 | Total Energy per hour (mWh) | 187.510 | 37.085
Total Energy (per hour) (mWh): |  | 300.412 | 79.436
Total Energy (per hour) (mWh): |  | 200.973
Total Energy (per day) (mWh): |  | 4823.351

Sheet: Expected Battery Life
Expected Battery Life
Manufacturer | Nominal Voltage (V) | Capacity (mAh) | Price (€) | Capacity (mWh) | Expected Battery Life (days)
RS Components | 3.7 | 2000 | 22.33 € | 7400 | 1.53
 | 3.7 | 5200 | 23.46 € | 19240 | 3.99
 | 3.7 | 7800 | 30.05 € | 28860 | 5.98
 | 3.7 | 10400 | 36.88 € | 38480 | 7.98
 | 5.0 | 20000 | 27.70 € | 100000 | 20.73

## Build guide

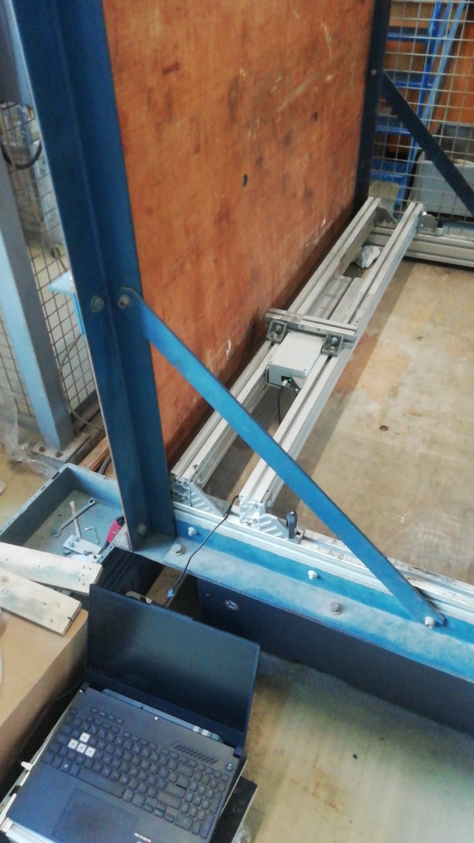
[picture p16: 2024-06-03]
Tests and Results/Vibration Validation Test/Setup Images/IMG-20240514-WA0007.jpg

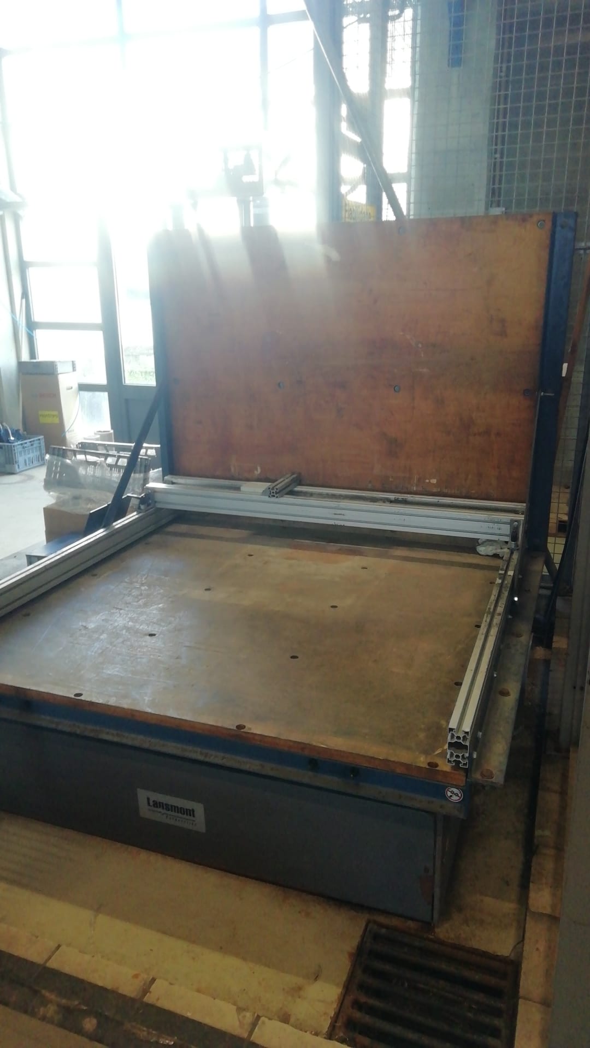
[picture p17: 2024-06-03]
Tests and Results/Vibration Validation Test/Setup Images/IMG-20240514-WA0008.jpg

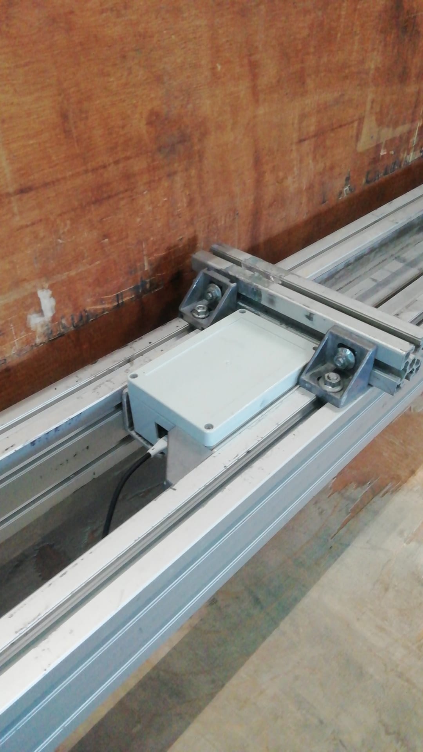
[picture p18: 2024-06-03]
Tests and Results/Vibration Validation Test/Setup Images/IMG-20240514-WA0014.jpg

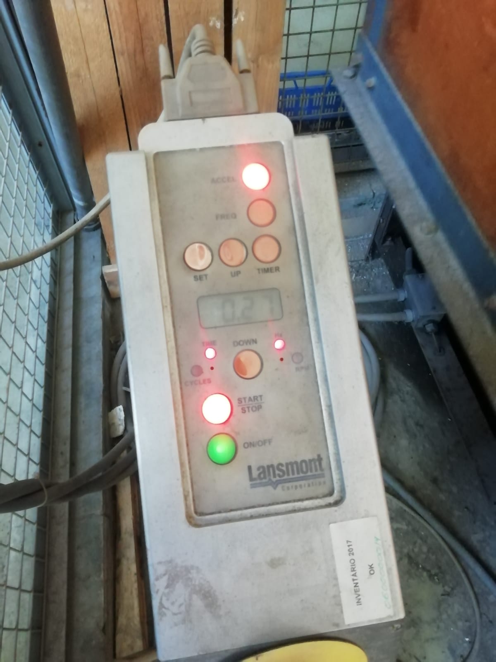
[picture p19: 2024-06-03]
Tests and Results/Vibration Validation Test/Setup Images/IMG-20240514-WA0006.jpg

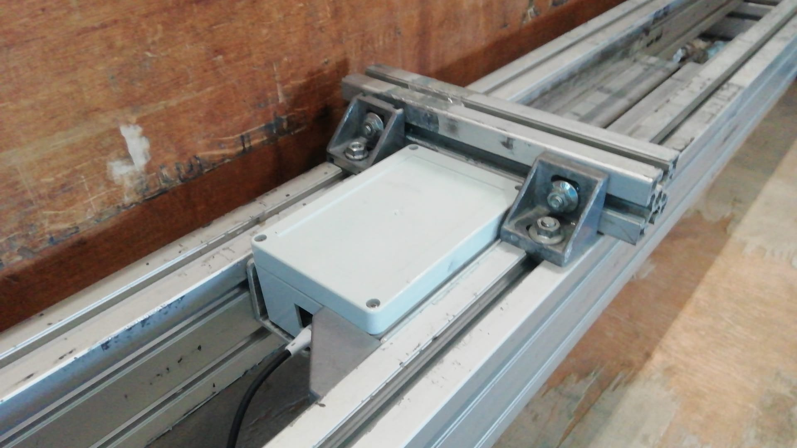
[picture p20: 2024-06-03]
Tests and Results/Vibration Validation Test/Setup Images/IMG-20240514-WA0009.jpg

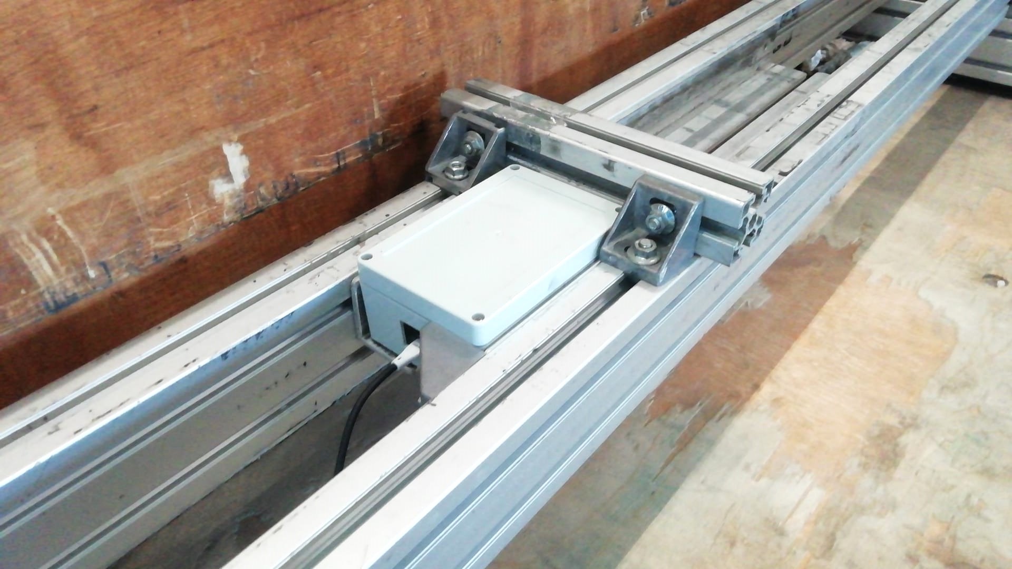
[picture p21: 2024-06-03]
Tests and Results/Vibration Validation Test/Setup Images/IMG-20240514-WA0010.jpg

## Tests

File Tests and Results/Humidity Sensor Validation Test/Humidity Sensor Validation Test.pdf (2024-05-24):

## Humidity Sensor Validation Test

May 24, 2024

[131]: import pandas as pd import matplotlib.pyplot as plt
import numpy as np
from IPython.display import display, Markdown

# Step 1: Read the CSV file

csv_file_path = 'bme_data_teste_humidade.csv' # Using double backslashes if␣ ↪needed
df = pd.read_csv(csv_file_path, names=['timestamp', 'temperature', 'humidity',␣ ↪'pressure'])

# Convert the 'timestamp' column from epoch to datetime format df['timestamp'] = pd.to_datetime(df['timestamp'], unit='s')

# Calculate the relative minutes after the first measurement df['relative_minutes'] = (df['timestamp'] - df['timestamp'].min()) / pd. ↪Timedelta('1 minute')

# Assuming the CSV columns are named 'timestamp', 'temperature', 'humidity',␣ ↪'pressure'

time_data = df['relative_minutes']
temperature_data = df['temperature']
humidity_data = df['humidity']

def calculate_cycle_average(time_data, humidity_data, start, end): soma = 0
contador = 0

for x in time_data:
if start <= x <= end:
contador += 1
soma += np.interp(x, time_data, humidity_data)

if contador == 0:
return 0 # To avoid division by zero
return soma / contador

# Calculate averages for different cycles

average_20_percent_cycle = calculate_cycle_average(time_data, humidity_data, 4,␣ ↪23)
average_40_percent_cycle = calculate_cycle_average(time_data, humidity_data,␣ ↪40, 60)
average_80_percent_cycle = calculate_cycle_average(time_data, humidity_data,␣ ↪64, 84)

# Display the calculated averages using Markdown headers

markdown_content = f"""
### Cycle Averages

**Average of the 20% Cycle:** {average_20_percent_cycle:.2f}%

**Average of the 40% Cycle:** {average_40_percent_cycle:.2f}%

**Average of the 80% Cycle:** {average_80_percent_cycle:.2f}% """
display(Markdown(markdown_content))

# Step 2: Plot the data

plt.figure(figsize=(15, 7))

# Humidity plot using interpolated line with relative minutes plt.plot(time_data, humidity_data, label='Humidity')

plt.plot(time_data, temperature_data, label='Temperature') plt.fill_between(time_data, humidity_data, color='skyblue', alpha=0.3) # Fill␣ ↪the area under the line

plt.grid(True, linestyle='-.')
plt.tick_params(labelcolor='black', labelsize='medium', width=1) plt.xlabel('Relative Minutes After First Measurement') plt.ylabel('Values')

# Set y-axis limits

plt.ylim(0, 100)
plt.xlim(0, 90)

plt.text(0.3, 60, "Start Test,\nChamber set to 20ºC and 20%", rotation=90,␣ ↪verticalalignment='bottom')

# Interesting Points

interesting_points = [
(4, "Start Cycle of 20%\n20 min. interval start"), (23, "End Cycle\nChamber set to 40%"),
(40, 'Start Cycle of 40%\n20 min. interval start'), (60, "End Cycle"),
(64, "Start Cycle of 80%\n20 min. interval start"),

(84, "End Cycle")
]

for x, text in interesting_points:
plt.axvline(x=x, color='black', linestyle='--')
# Find the y-value at the intersection

y_intersection = np.interp(x, time_data, humidity_data)
plt.scatter(x, y_intersection, color='red') # Mark the intersection point # Display the value on the y-axis
if x < 50:
plt.text(x+0.5, 60, f"{text}", rotation=90, verticalalignment='bottom') plt.text(x-3.5, y_intersection, f"{y_intersection:.2f}%", rotation=0,␣ ↪verticalalignment='bottom')
elif 50 <= x < 85:
plt.text(x+0.5, 1, f"{text}", rotation=90, verticalalignment='bottom') plt.text(x-3.5, y_intersection, f"{y_intersection:.2f}%", rotation=0,␣ ↪verticalalignment='bottom')
else:
plt.text(x-1, 1, f"{text}", rotation=90, verticalalignment='bottom') plt.text(x-3.5, y_intersection, f"{y_intersection:.2f}%", rotation=0,␣ ↪verticalalignment='bottom')

# Customize the plots

plt.tight_layout()
plt.legend(loc='upper right') # Add a legend in the top right corner

# Display the plot

plt.show()

### 0.0.1 Cycle Averages

Average of the 20% Cycle: 20.75%

Average of the 40% Cycle: 42.34%

Average of the 80% Cycle: 73.86%

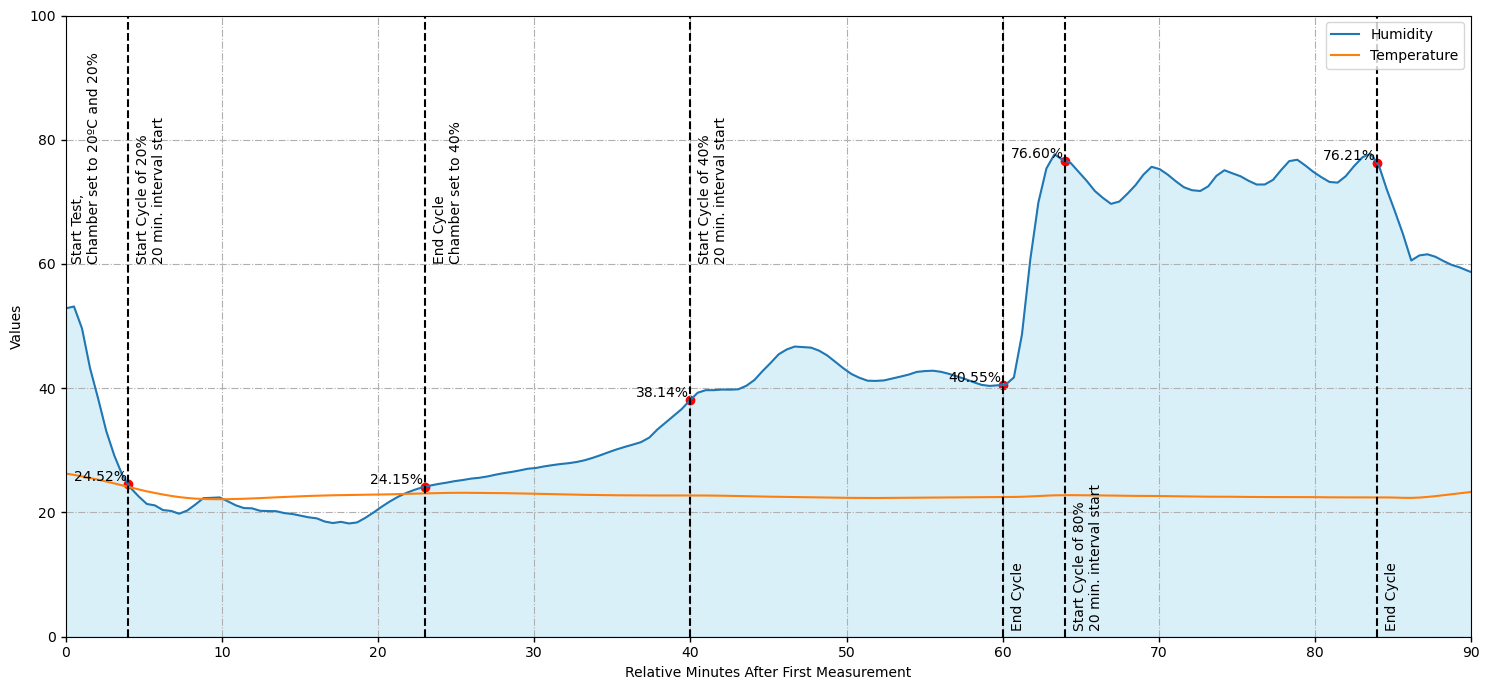
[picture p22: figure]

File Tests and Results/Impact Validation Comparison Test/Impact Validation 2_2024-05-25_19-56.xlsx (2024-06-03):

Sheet: General information
Usage | Impact Validation 2
Sensor ID | 4281433800B7
Type of sensor | ASPION G-Log 2
Profile name | test_profiles_impact
Negative shock threshold in g | -4
Positive shock threshold in g | 4
Shock duration threshold in ms | 5
Data rate in Hz | 200
Lower temperature threshold in °C | Disabled
Upper temperature threshold in °C | Disabled
Rel. humidity threshold in %rH | Disabled
Interval of activity events in Hour(s) | 1
BLE communication | Enabled
Timezone | (UTC+00:00) Dublin, Edimburgo, Lisboa, Londres
Start | 2024-05-25 20:56
Stop
Read | 2024-05-25 21:28

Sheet: Shock events
Type | Time | X axis in g | Y axis in g | Z axis in g | Negative shock threshold in g | Positive shock threshold in g
Shock | 2024-05-25 21:00 | 6.72 | 15.94 | 10.37 | -4 | 4
Shock | 2024-05-25 21:00 | -1.73 | -7.3 | 15.94 | -4 | 4
Shock | 2024-05-25 21:00 | 4.99 | 15.94 | 15.94 | -4 | 4
Shock | 2024-05-25 21:00 | 15.94 | -12.67 | -15.94 | -4 | 4
Shock | 2024-05-25 21:00 | -15.94 | -2.3 | 15.94 | -4 | 4
Shock | 2024-05-25 21:00 | -9.79 | 15.94 | 15.94 | -4 | 4
Shock | 2024-05-25 21:27 | -5.38 | -7.87 | 13.06 | -4 | 4
Shock | 2024-05-25 21:27 | -5.57 | -4.8 | 15.94 | -4 | 4
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

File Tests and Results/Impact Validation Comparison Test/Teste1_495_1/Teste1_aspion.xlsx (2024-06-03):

Milliseconds | 0 | 5 | 10 | 15 | 20 | 25 | 30 | 35 | 40 | 45 | 50 | 55 | 60 | 65 | 70 | 75 | 80 | 85 | 90
X axis in g | 0 | 0 | 0 | 0 | 6.72 | -2.5 | -1.73 | 0.19 | -0.58 | 0 | -0.19 | 0 | -0.19 | 0.19 | -0.19 | -0.19 | -0.38 | 0.19 | 0.96
Y axis in g | 0 | 0 | 0 | 0 | 15.94 | -5.95 | 0.58 | 0.58 | -1.54 | 1.54 | -0.19 | 0.19 | 0 | -0.19 | 0 | -1.73 | -3.65 | -0.58 | 0.96
Z axis in g | 0 | 0 | 0 | 0 | 10.37 | -1.92 | 4.42 | -5.57 | 6.53 | -5.76 | 1.73 | 0.19 | -1.15 | 1.34 | -1.15 | 2.3 | 2.11 | 0.58 | 1.73

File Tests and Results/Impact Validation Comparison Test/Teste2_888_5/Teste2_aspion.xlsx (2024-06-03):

Milliseconds | 0 | 5 | 10 | 15 | 20 | 25 | 30 | 35 | 40 | 45 | 50 | 55 | 60 | 65 | 70 | 75 | 80 | 85 | 90
X axis in g | 0 | 0 | 0 | 0 | 0.77 | -9.79 | 0.58 | 0.58 | 0.19 | 0 | -0.19 | 0.19 | -0.19 | 0.19 | -0.19 | 0 | 0 | 0.19 | 1.92
Y axis in g | 0 | 0 | 0 | 0 | -15.94 | 15.94 | -3.84 | -2.3 | 1.54 | -0.58 | 0 | 0.38 | -0.77 | 0.38 | -0.19 | 0 | -0.19 | 0 | 1.73
Z axis in g | -0.19 | 0 | 0 | 0.19 | 15.94 | 15.94 | -15.94 | 9.22 | -9.41 | 7.3 | -1.34 | -1.73 | 1.92 | -2.11 | 1.34 | -0.58 | 0 | 0.38 | 0

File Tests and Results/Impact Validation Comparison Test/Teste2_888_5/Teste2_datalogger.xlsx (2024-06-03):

Milliseconds | 0 | 5 | 10 | 15 | 20 | 25 | 30 | 35 | 40 | 45 | 50 | 55 | 60 | 65 | 70 | 75 | 80 | 85 | 90 | 95 | 100 | 105 | 110 | 115 | 120 | 125 | 130 | 135 | 140 | 145 | 150 | 155 | 160 | 165 | 170 | 175 | 180 | 185 | 190 | 195 | 200 | 205
X axis in g | 0.0234 | 4.6235 | -3.9595 | -0.3525 | -0.0156 | -0.146 | -0.0601 | -0.0029 | -0.167 | 0.1387 | 0.1694 | 1.9395 | 0.1025 | -0.2886 | -0.2837 | -0.1265 | 0.0117 | 0.0127 | 0.042 | 0.1831 | 0.936 | -0.1978 | -0.2671 | -0.1387 | -0.0396 | 0.0303 | -0.0698 | -0.0356 | -0.0381 | -0.0337 | -0.0254 | -0.0073 | -0.0254 | -0.0283 | -0.02 | -0.0225 | -0.0229 | -0.0273 | -0.0278 | -0.0244 | -0.0283 | -0.0264
Y axis in g | -0.0283 | -0.7817 | -3.5566 | -0.645 | 0.1768 | 0.5728 | 0.2534 | -0.2378 | 0.9058 | 0.0151 | -0.1235 | -0.8799 | -0.2446 | 0.3354 | 0.5117 | 0.123 | -0.0537 | -0.1411 | -0.1094 | -0.0986 | -0.1162 | -0.4395 | -0.0957 | 0.0742 | 0.1592 | -0.0508 | -0.1387 | -0.0225 | -0.0615 | -0.064 | -0.021 | 0 | -0.0356 | -0.0308 | -0.0283 | -0.0347 | -0.0342 | -0.0352 | -0.0303 | -0.0264 | -0.0366 | -0.0347
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

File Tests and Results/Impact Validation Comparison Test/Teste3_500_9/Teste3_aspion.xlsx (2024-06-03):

Milliseconds | 0 | 5 | 10 | 15 | 20 | 25 | 30 | 35 | 40 | 45 | 50 | 55 | 60 | 65 | 70 | 75 | 80 | 85 | 90
X axis in g | 0 | 0 | 6.14 | -2.11 | -7.87 | 0 | -0.19 | -0.58 | 0.19 | -0.38 | 0.58 | 1.34 | 0.38 | -0.96 | -1.15 | 0 | -0.38 | -0.38 | -0.77
Y axis in g | 0 | 0 | -7.1 | -3.65 | 4.61 | 0.38 | 0.77 | 0.58 | 0.58 | -0.58 | 0 | 0 | -0.38 | 0.77 | -0.19 | 0.38 | -0.19 | 0.19 | 0.19
Z axis in g | 0 | 0 | 3.84 | 4.61 | 9.98 | 15.94 | -2.5 | -0.38 | -1.73 | 0.77 | -0.77 | 0.58 | 1.92 | 4.8 | 1.54 | 0.77 | 0.19 | 0.77 | 0.96

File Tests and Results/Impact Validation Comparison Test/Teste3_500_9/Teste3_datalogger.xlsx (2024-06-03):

Milliseconds | 0 | 5 | 10 | 15 | 20 | 25 | 30 | 35 | 40 | 45 | 50 | 55 | 60 | 65 | 70 | 75 | 80 | 85 | 90 | 95 | 100 | 105 | 110 | 115 | 120 | 125 | 130 | 135 | 140 | 145 | 150 | 155 | 160 | 165 | 170 | 175 | 180
X axis in g | -0.0142 | -1.4297 | 0.6665 | 6.0767 | -0.2212 | 0.1074 | 0.043 | 0.0322 | 0.0195 | 0.0566 | 0.0171 | -0.0581 | -0.4365 | -0.4541 | -0.7832 | -1.4517 | -0.1514 | -0.1118 | -0.1118 | 0.0312 | 0.0776 | -0.0654 | -0.0308 | -0.0498 | -0.0562 | -0.0327 | -0.0254 | -0.0117 | -0.0322 | -0.0459 | -0.0352 | -0.0269 | -0.0288 | -0.0303 | -0.0303 | -0.0303 | -0.0273
Y axis in g | -0.0366 | -2.9609 | 1.5601 | 0.3872 | -0.688 | 0.1309 | 0.4575 | 0.6099 | 0.2168 | -0.0601 | -0.1743 | -0.062 | -0.3418 | 0.0518 | 0.0522 | 0.7578 | 0.2837 | -0.1279 | -0.0469 | -0.3774 | -0.2974 | -0.0034 | 0.0742 | 0 | 0.022 | -0.0073 | -0.0605 | -0.0728 | -0.0308 | -0.0107 | -0.0137 | -0.0352 | -0.0264 | -0.0303 | -0.0259 | -0.0283 | -0.0312
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

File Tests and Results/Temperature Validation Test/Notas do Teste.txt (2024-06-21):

Modelo do Forno - 

1712135723 - começou a crescer a temperatura de 28 para 30
1712135723 - AMPROBE TR300 marca outside 25.1ºC e 42.2% humidade relativa
1712136096 - Forno marca 30ºC - começa os 20 min 
1712137335 - Fim dos 20 min - subir ate 40ºC
1712137480 - Forno marca 35ºC
1712137624 - Forno marca 40ºC - Iniciar 20 minutos
1712138951 - Fim dos 20 min - subir até 50ºC
1712139143 - Forno marca 45ºC
1712139285 - Forno marca 50ºC - Iniciar 40 minutos
1712141792 - Fim dos 40 min - desligar forno e meter ca fora os data loggers
1712142151 - TR300 AMPPROBE marca 26.1ºC 38.9%
1712148797 - TR300 AMPPROBE marca 25.0ºC 43.7%

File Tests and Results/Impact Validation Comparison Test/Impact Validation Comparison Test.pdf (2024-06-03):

## Impact Validation Comparison Test

May 27, 2024

[28]: import pandas as pd
import matplotlib.pyplot as plt import numpy as np

# Calculate extended statistics def calculate_statistics(data): return {

'mean': np.mean(data),
'std': np.std(data),
'min': np.min(data),
'max': np.max(data),
'median': np.median(data)
}

# Load the data

for i in range(3):

#Test1_495_1

if i==0:
aspion_df = pd.read_excel('Teste1_495_1/Teste1_aspion.xlsx') datalogger_df = pd.read_excel('Teste1_495_1/Teste1_datalogger.xlsx')

#Test2_888_5

elif i==1:
aspion_df = pd.read_excel('Teste2_888_5/Teste2_aspion.xlsx') datalogger_df = pd.read_excel('Teste2_888_5/Teste2_datalogger.xlsx')

#Test3_500_9

elif i==2:
aspion_df = pd.read_excel('Teste3_500_9/Teste3_aspion.xlsx') datalogger_df = pd.read_excel('Teste3_500_9/Teste3_datalogger.xlsx')

# Extract the time and acceleration data

time_aspion = aspion_df.columns[1:].astype(int)
time_datalogger = datalogger_df.columns[1:].astype(int)

x_aspion = aspion_df.iloc[0, 1:].astype(float)

y_aspion = aspion_df.iloc[1, 1:].astype(float)
z_aspion = aspion_df.iloc[2, 1:].astype(float) magnitude_aspion =␣
↪(x_aspion*x_aspion+y_aspion*y_aspion+z_aspion*z_aspion)**0.5

x_datalogger = datalogger_df.iloc[0, 1:].astype(float) y_datalogger = datalogger_df.iloc[1, 1:].astype(float)
z_datalogger = datalogger_df.iloc[2, 1:].astype(float)
magnitude_datalogger =␣
↪(x_datalogger*x_datalogger+y_datalogger*y_datalogger+z_datalogger*z_datalogger)**0.

↪5

# Plot the data

plt.figure(figsize=(15, 10))

plt.subplot(4, 1, 1)
plt.plot(time_aspion, x_aspion, label='Aspion X-axis', marker='o') plt.plot(time_datalogger, x_datalogger, label='Datalogger X-axis',␣ ↪linestyle='--', marker='x')
plt.title('X-axis Impact Comparison')
plt.xlabel('Time (ms)')
plt.ylabel('Acceleration (g)')
plt.legend()

plt.subplot(4, 1, 2)
plt.plot(time_aspion, y_aspion, label='Aspion Y-axis', marker='o') plt.plot(time_datalogger, y_datalogger, label='Datalogger Y-axis',␣ ↪linestyle='--', marker='x')
plt.title('Y-axis Impact Comparison')
plt.xlabel('Time (ms)')
plt.ylabel('Acceleration (g)')
plt.legend()

plt.subplot(4, 1, 3)
plt.plot(time_aspion, z_aspion, label='Aspion Z-axis', marker='o') plt.plot(time_datalogger, z_datalogger, label='Datalogger Z-axis',␣ ↪linestyle='--', marker='x')
plt.title('Z-axis Impact Comparison')
plt.xlabel('Time (ms)')
plt.ylabel('Acceleration (g)')
plt.legend()

plt.subplot(4, 1, 4)
plt.plot(time_aspion, magnitude_aspion, label='Aspion Z-axis', marker='o') plt.plot(time_datalogger, magnitude_datalogger, label='Datalogger Z-axis',␣ ↪linestyle='--', marker='x')

plt.title('All-axis magnitude Impact Comparison') plt.xlabel('Time (ms)')
plt.ylabel('Acceleration (g)')
plt.legend()

plt.tight_layout()
plt.show()

aspion_stats = {
'X': calculate_statistics(x_aspion),
'Y': calculate_statistics(y_aspion),
'Z': calculate_statistics(z_aspion),
'magnitude': calculate_statistics(magnitude_aspion) }

datalogger_stats = {
'X': calculate_statistics(x_datalogger),
'Y': calculate_statistics(y_datalogger),
'Z': calculate_statistics(z_datalogger),
'magnitude': calculate_statistics(magnitude_datalogger) }

# Create a DataFrame for display stats_df = pd.DataFrame({

'Aspion X': aspion_stats['X'], 'Datalogger X': datalogger_stats['X'], 'Aspion Y': aspion_stats['Y'], 'Datalogger Y': datalogger_stats['Y'], 'Aspion Z': aspion_stats['Z'],
'Datalogger Z': datalogger_stats['Z'],
'Aspion Magnitude': aspion_stats['magnitude'], 'Datalogger Magnitude': datalogger_stats['magnitude'] }).T

display(stats_df)

mean | std | min | max | median
Aspion X | 0.121053 1.713384 -2.500000 | 6.720000 0.000000
Datalogger X | -0.012361 0.772736 -2.313500 | 4.075200 -0.028300
Aspion Y | 0.313684 4.043931 -5.950000 15.940000 0.000000
Datalogger Y | -0.159646 1.293331 -8.648900 | 0.819800 -0.013200
Aspion Z | 0.828947 3.591570 -5.760000 10.370000 0.190000
Datalogger Z | 1.420030 2.843392 -5.320800 14.376000 0.994400
Aspion Magnitude | 3.466291 4.579681 0.000000 20.168760 1.750743
Datalogger Magnitude 1.828406 3.008947 0.106128 17.264996 1.000836

mean | std | min | max | median
Aspion X | -0.302632 2.286215 -9.790000 | 1.920000 0.000000
Datalogger X | 0.040571 1.002649 -3.959500 | 4.623500 -0.025900
Aspion Y | -0.202105 5.301844 -15.940000 15.940000 0.000000
Datalogger Y | -0.121655 0.615820 -3.556600 | 0.905800 -0.034950
Aspion Z | 1.101579 7.186672 -15.940000 15.940000 0.000000
Datalogger Z | 1.212302 1.631538 -2.109900 | 7.411600 0.995600
Aspion Magnitude | 5.411021 7.553234 | 0.000000 24.576641 1.781404
Datalogger Magnitude 1.534409 1.782742 | 0.132587 | 9.124629 1.000962

mean | std | min | max | median
Aspion X | -0.323158 2.384816 -7.870000 | 6.140000 -0.190000
Datalogger X | 0.036349 1.073402 -1.451700 | 6.076700 -0.030300
Aspion Y | -0.191579 2.140583 -7.100000 | 4.610000 0.000000
Datalogger Y | -0.025559 0.604767 -2.960900 | 1.560100 -0.026400
Aspion Z | 2.173158 4.243280 -2.500000 15.940000 0.770000
Datalogger Z | 1.060400 2.772875 -3.003400 15.999500 0.995100
Aspion Magnitude | 3.526533 4.549965 0.000000 15.944529 1.460137
Datalogger Magnitude 1.710927 2.721383 0.107989 16.333860 1.002793

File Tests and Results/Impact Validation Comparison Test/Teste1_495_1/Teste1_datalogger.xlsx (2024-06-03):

Milliseconds | 0 | 5 | 10 | 15 | 20 | 25 | 30 | 35 | 40 | 45 | 50 | 55 | 60 | 65 | 70 | 75 | 80 | 85 | 90 | 95 | 100 | 105 | 110 | 115 | 120 | 125 | 130 | 135 | 140 | 145 | 150 | 155 | 160 | 165 | 170 | 175 | 180 | 185 | 190 | 195 | 200 | 205 | 210 | 215 | 220 | 225
X axis in g | -0.0273 | -2.3135 | 4.0752 | -0.3091 | 0.5405 | -0.231 | 0.0244 | -0.0293 | 0.0571 | -0.0044 | -0.2319 | -1.1045 | -0.4131 | -0.0454 | -0.063 | -0.2349 | 0.0425 | 1.5957 | 0.5142 | -0.0181 | -0.0815 | -0.1826 | -0.4331 | -0.4526 | -0.4551 | -0.2017 | -0.0562 | -0.1079 | -0.1929 | -0.0767 | 0.0293 | 0.0444 | 0.0469 | 0.0034 | -0.0322 | -0.0254 | -0.0317 | -0.0317 | -0.0234 | -0.0093 | -0.0142 | -0.0259 | -0.0264 | -0.0264 | -0.0132 | -0.0166
Y axis in g | -0.0034 | -0.4443 | -8.6489 | 0.2983 | -0.7534 | 0.3647 | -0.0771 | -0.1128 | 0.0073 | 0.0894 | 0.1963 | 0.8198 | 0.5342 | -0.0132 | -0.0449 | -0.3403 | -0.5718 | 0.1421 | 0.6992 | 0.1162 | 0.0903 | 0.0908 | 0.2603 | 0.1523 | -0.2603 | -0.1113 | 0.1763 | 0.1821 | 0.1924 | 0.1221 | 0.0234 | -0.0493 | -0.0991 | -0.1113 | -0.0132 | -0.0098 | 0.0068 | -0.0205 | -0.0332 | -0.0376 | -0.0293 | -0.0195 | -0.019 | -0.0288 | -0.0259 | -0.0298
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

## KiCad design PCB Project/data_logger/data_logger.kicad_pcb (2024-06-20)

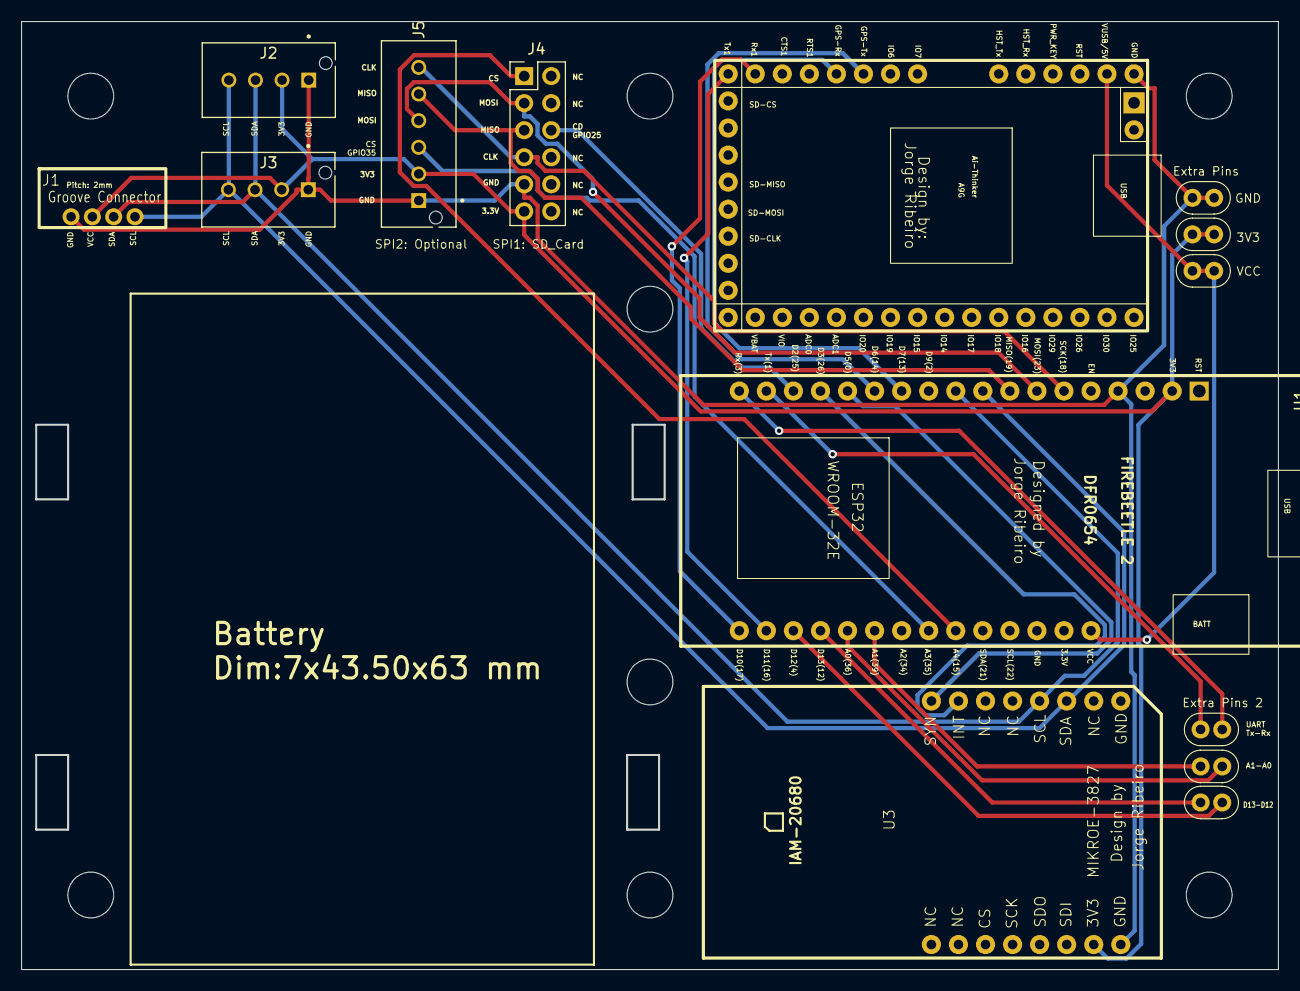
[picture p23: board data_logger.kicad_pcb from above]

Board: 2 copper layers, 118.0 x 89.0 mm, 22 parts (0 on the bottom side), 23 nets.

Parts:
J1: GrooveConnector_1
J2, J3: TE_1744418-4
J4: SD Connector; PinHeader_2x06_P2.54mm_Vertical
J5: SPI Connector Optional; TE_1744418-6
J6, J7, J8, J9, J10, J11: Conn_01x02; extraconnectors_1x02_P2.54mm
REF1, REF2, REF3, REF4, REF5, REF6, REF7, REF8: MountingHole_4.3mm_M4
U1: MODULE_DFR0654
U2: A9G-Kit
U3: MIKROE-3827

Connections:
+3V3: J1.2 (VCC), J2.2 (VCC), J3.2 (VCC), J4.6, J5.2, J6.1, J6.2, U1.2 (3.3V), U3.7 (3V3)
+5V: J7.1, J7.2, U1.19 (VCC), U2.37 (VUSB/5V)
Earth: J1.1 (GND), J2.1 (GND), J3.1 (GND), J4.5, J5.1, J8.1, J8.2, U1.4 (GND), U2.38 (GND), U3.8 (GND)
unnamed: J1.4 (SCL), J2.4 (SCL), J3.4 (SCL), U1.9 (SCL), U3.14 (SDA)
unnamed: J1.3 (SDA), J2.3 (SDA), J3.3 (SDA), U1.10 (SDA), U3.13 (SCL)
unnamed: J4.1, U1.24 (A4)
unnamed: J4.2, J5.4, U1.7 (MOSI)
unnamed: J4.3, J5.5, U1.8 (MISO)
unnamed: J4.4, J5.6, U1.6 (SCK)
unnamed: J4.9, U1.16 (D2)
unnamed: J5.3, U1.25 (A3)
unnamed: J9.1, U1.17 (TX)
unnamed: J9.2, U1.18 (RX)
unnamed: J10.1, U1.27 (A1)
unnamed: J10.2, U1.28 (A0)
unnamed: J11.1, U1.29 (D13)
unnamed: J11.2, U1.30 (D12)
unnamed: U1.15 (D3), U3.10 (INT)
unnamed: U1.14 (D5), U3.9 (SYN)
unnamed: U1.13 (D6), U2.30 (GPS_TX)
unnamed: U1.12 (D7), U2.29 (GPS_RX)
unnamed: U1.32 (D10/UART2-Tx), U2.26 (RX1)
unnamed: U1.31 (D11/UART2-Rx), U2.25 (TX1)

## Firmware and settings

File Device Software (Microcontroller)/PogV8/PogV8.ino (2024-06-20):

#include <FS.h>
#include <SD.h>
#include <SPI.h>
#include <Wire.h>
#include <Adafruit_BME680.h>
#include <ESP32Time.h>
#include <HardwareSerial.h>
#include <esp_system.h>
#include <esp_adc_cal.h>
#include <LittleFS.h>
#include <Arduino.h>
#include <arduinoFFT.h>
#include <ArduinoJson.h>


//////////////////////  SPI Configurations  //////////////////////////
//SPI Pinouts
const int32_t SD_SS_PIN = 18;
const int32_t SD_CS_PIN = 15;
const int32_t SD_MO_PIN = 23;
const int32_t SD_MI_PIN = 19;

SPIClass serial_peripheral_interface = SPIClass(VSPI);


//////////////////    I2C Configurations    //////////////////////////
#define SDA_PIN 21  // SDA Pin for I2C Bus Line
#define SCL_PIN 22  // SCL Pin for I2C Bus Line

#define IMU_ADDRESS 0x69  // I2C address of the IMU
#define BME_ADDRESS 0x76  //I2C address of the BME

#define LED_PIN 2         // LED connected to GPIO 2
#define BUTTON_PIN 27     // Button connected to GPIO 27
#define DEBOUNCE_TIME 50  // Debounce time in milliseconds

#define FORMAT_LITTLEFS_IF_FAILED true

Adafruit_BME680 bme;  //Uses of the Adrafuit library

//////////////////    UART Configurations    //////////////////////////
HardwareSerial SerialPortA9G(2);  // use UART2
HardwareSerial SerialPortGPS(1);

////////////////////// Definitions of Constants //////////////////////

String data_logger_id = "device_2";               //UNIC ID OF THE DEVICE
String adress_broker_mqtt = "broker.hivemq.com";  // "172.187.90.157";  //MQTT address
int port_broker_mqtt = 1883;                      //MQTT Port
String apn = "net2.vodafone.pt";                  // Define the APN of the SIM Network, in this case, vodafone.

///////// Definitions of Global Variables of the Program /////////////
bool remote_configuration = true;  // This enables the remote configuration function. If false, the configurations below are used.

// This configurations are by default, just to define the variables.
unsigned long start_timer = 0;

bool sleep_mode = false;                                //Enable of the sleep mode function
unsigned long interval_to_sleep_mode = 10 * 60 * 1000;  // Default 10 minutes without movement (Conversion for miliseconds)
float movement_detection_threshold = 0.3;               //Default 0.3 g

bool bme_mode = true;                               //Enable of the bme data recording
unsigned long bme_interval_timer = 20 * 60 * 1000;  //Default 20 minutes (Conversion for miliseconds)
int interval_bme_recording = 10;                    //Default 10 seconds (Sample Time Recording)

bool gps_mode = false;                     //Enable of the gps data recording
long gps_interval_timer = 60 * 60 * 1000;  //Default 60 minutes (Conversion for miliseconds)
int max_time_try_location = 60;            //In Seconds

int accelerometer_scale = 8;  //Selection of the accelerometer scale: ONLY 2, 4, 8, 16 g!
int sample_rate = 200;        //Hz

bool impact_mode = false;     //Enable of the impact recording function
float impact_threeshold = 5;  //Default 5 g - Impact Threeshold

bool vibration_mode = false;                    //Enable of the vibration recording function
int n_vibration_per_sample = 512;               // Default 512 points (Not tested other points values)
float vibration_magnitude_threshold = 0.01;     //Default threshold of vibration recording for each frequency
long vibration_interval_timer = 2 * 60 * 1000;  //Default interval of 2 minutes for vibration sample recording

bool mqtt_mode = true;                      //Enable of the real time comunication
long mqtt_interval_timer = 30 * 60 * 1000;  //Default interval of 30 minutes for communication of the data

bool logs_mode = false;                          //Enable the log recording
bool esp_stats_mode = true;                      //Enable recording of statistics (such as battery voltage)
long esp_stats_interval_timer = 15 * 60 * 1000;  //Default value of 15 minutes for recording statistics (conversion to miliseconds)

////////////////////////////////////////////////////////////////////////////////////

//Definition of enums
enum log_message_type {
  INFO,
  WARNING,
  ERROR,
  FATAL_ERROR
};

//Definition of Structs
struct accelerometer_data_struct {
  float accelx;
  float accely;
  float accelz;
};

struct impact_data_struct {
  unsigned long time;
  int millis;
  float accelx;
  float accely;
  float accelz;
};

struct vibration_data_struct {
  unsigned long time;
  float frequency;
  float magnitude;
};

struct bme_data_struct {
  unsigned long epochTime;
  float temperatureMean;
  float humidityMean;
  float pressureMean;
};

struct gps_data_struct {
  unsigned long time;
  String latitude;
  String N_S;
  String longitude;
  String E_W;
  int fix;
  int satellites;
  float HDOP;
  float altitude;
  String units;
  float geoidalSeparation;
  String units2;
};

struct esp_stats_struct {
  unsigned long time;
  float ram_usage;
  float battery_voltage;
  int n_valueswaiting_accelerometer_data_queue;
  int n_valueswaiting_bme_data_queue;
  int n_valueswaiting_gps_data_queue;
};


//Definition of variables of decision
volatile bool interruptFlag_movement = false;
volatile bool order_to_communicate_MQTT = true;    //This variable will controll the comunication
bool connection_configurated_sucessfully = false;  //mqtt to sd
bool request_samples_vibration = false;
volatile bool order_to_turn_off = false;
volatile bool order_to_sleep = false;
volatile bool order_to_read_imu = false;
unsigned long buttonPressTime = 0;


///////////// Definition of Interrupt Functions //////////////////////
// Interrupt Service Routine when button is pressed
void IRAM_ATTR buttonPressed() {
  buttonPressTime = millis();  // Record the time the button was pressed
}

// Interrupt Service Routine when button is released
void IRAM_ATTR buttonReleased() {
  const unsigned long press_time_to_turn_off = 3000;  // Required press time in milliseconds (3 seconds)

  if ((millis() - buttonPressTime) >= press_time_to_turn_off) {  // Check if the button was held long enough
    order_to_turn_off = true;
    xTaskCreate(blinkLEDTask, "Blink LED Task", 1024, NULL, 1, NULL);  // Create the task
  }
}

// Interrupt Service Routine when the imu_reading_timer expires
void IRAM_ATTR imu_reading_timer() {
  order_to_read_imu = true;
}


///////////// Definition of FreeRtos Components //////////////////////
// Definitions of Task Handles
TaskHandle_t esp_manager_task_handle;
TaskHandle_t imu_reading_task_handle;
TaskHandle_t vibration_processing_task_handle;
TaskHandle_t bme_reading_task_handle;
TaskHandle_t gps_manager_task_handle;
TaskHandle_t sd_communication_task_handle;
TaskHandle_t esp_stats_task_handle;
TaskHandle_t mqtt_communication_task_handle;
TaskHandle_t led_blink_task_handle;

//Definitions of Queues
QueueHandle_t impact_data_queue = xQueueCreate(2000, sizeof(impact_data_struct));
QueueHandle_t vibration_data_queue = xQueueCreate(1000, sizeof(vibration_data_struct));
QueueHandle_t vibration_sample_queue = xQueueCreate(n_vibration_per_sample, sizeof(accelerometer_data_struct));

QueueHandle_t bme_data_queue = xQueueCreate(100, sizeof(bme_data_struct));
QueueHandle_t gps_data_queue = xQueueCreate(50, sizeof(gps_data_struct));
QueueHandle_t esp_stats_queue = xQueueCreate(100, sizeof(esp_stats_struct));
QueueHandle_t log_data_queue = xQueueCreate(100, sizeof(char[100]));

//Definition of Semaphores
SemaphoreHandle_t i2cSemaphore = xSemaphoreCreateMutex();
SemaphoreHandle_t A9G_usageSemaphore = xSemaphoreCreateMutex();
SemaphoreHandle_t sd_Semaphore = xSemaphoreCreateMutex();
SemaphoreHandle_t internal_memory_Semaphore = xSemaphoreCreateMutex();

//////////////////    RTC Configurations    //////////////////////////
ESP32Time rtc(0);  // offset in seconds GMT


/////////////////////////////////////////////////////////////////////
/////////////////////  SETUP FUNCTION   /////////////////////////////
void setup() {

  Serial.begin(115200);
  SerialPortA9G.begin(115200, SERIAL_8N1);

  pinMode(SD_CS_PIN, OUTPUT);
  pinMode(25, INPUT);

  //Interrupt Pin - IMU: If detects movement turns HIGH
  pinMode(26, INPUT);

  pinMode(LED_PIN, OUTPUT);     // Set the LED pin as output
  digitalWrite(LED_PIN, HIGH);  //Turn on for configuration

  pinMode(BUTTON_PIN, INPUT_PULLUP);                                           // Set the button pin as input with pull-up resistor
  attachInterrupt(digitalPinToInterrupt(BUTTON_PIN), buttonPressed, FALLING);  // Attach interrupt for button press
  attachInterrupt(digitalPinToInterrupt(BUTTON_PIN), buttonReleased, RISING);  // Attach interrupt for button release

  serial_peripheral_interface.begin(SD_SS_PIN, SD_MI_PIN, SD_MO_PIN, SD_CS_PIN);

  Wire.begin(SDA_PIN, SCL_PIN);  // Start the I2C bus

  Serial.println("Starting with a delay of 2000ms");
  delay(2000);

  //Making the remote configuration
  if (!LittleFS.begin(FORMAT_LITTLEFS_IF_FAILED)) {
    Serial.println("LittleFS Mount Failed");
  }
  testing_sd();
  LittleFS.end();

  //Remote Configuration of variables of the ESP (Function in FreeRTOS_FUNCTIONS.ino)
  if (remote_configuration == true) {
    config_esp();
  }

  //Configuration of the timer of the imu
  hw_timer_t* timer = NULL;         // Pointer to the hardware timer instance
  timer = timerBegin(0, 80, true);  // Timer 0, prescaler of 80 (80 MHz / 80 = 1 MHz), count up
  timerAttachInterrupt(timer, &imu_reading_timer, true);
  uint32_t timer_interval_ticks = 1000000 / sample_rate;  // Convert sample rate to timer ticks
  timerAlarmWrite(timer, timer_interval_ticks, true);
  timerAlarmEnable(timer);

  //Definition and Start of The ESP Manager Task
  xTaskCreatePinnedToCore(esp_manager_task, "Task MSG", 8000, NULL, 5, &esp_manager_task_handle, 1);
}

/////////////////////////////////////////////////////////////////////
////////////////////  ESP MANAGER TASk  /////////////////////////////

void esp_manager_task(void* parameter) {

  //Configuration of the Sensors
  log(INFO, "esp-manager-task", "Starting to Configurating the Sensors");
  imu_config_accelerometer();
  bme_config();

  //Configuration of the A9G Module
  if (xSemaphoreTake(A9G_usageSemaphore, portMAX_DELAY)) {
    COM_Config("esp_manager_task");
    xSemaphoreGive(A9G_usageSemaphore);
  }

  digitalWrite(LED_PIN, LOW);  //Turn on for configuration

  Serial.println("ESP Manager started to managing tasks");

  unsigned long sleepmode_timer = millis() + interval_to_sleep_mode;

  unsigned long vibration_timer = millis() + 20 * 1000;
  unsigned long bme_timer = millis() + 0.5 * 60000;     //seconds
  unsigned long gps_timer = millis() + 0.5 * 60000;     //seconds
  unsigned long mqtt_timer = millis() + 2 * 60 * 1000;  //seconds
  unsigned long esp_stats_timer = millis() + 1 * 60 * 1000;

  //Normal State of the ESP
  while (1) {

    //Handling the Sleep Mode
    if (interruptFlag_movement == false && sleep_mode == true) {

      // If pin 26 has been low for more than 10 minutes, signal the sleep task
      if (millis() >= sleepmode_timer) {
        Serial.println("Entering in sleeping state mode");
        order_to_sleep = true;

        // Wait for crucial tasks to be suspended
        while (1) {
          bool allTasksSuspended = true;

          // Check if sd_communication_task_handle is not suspended
          if (sd_communication_task_handle == NULL) {
          } else if (eTaskGetState(sd_communication_task_handle) != eSuspended) {
            allTasksSuspended = false;
          }
          // Check if gps_manager_task_handle is not suspended
          if (gps_manager_task_handle == NULL) {
          } else if (eTaskGetState(gps_manager_task_handle) != eSuspended) {
            allTasksSuspended = false;
          }
          // Check if mqtt_communication_task_handle is not suspended
          if (mqtt_communication_task_handle == NULL) {
          } else if (eTaskGetState(mqtt_communication_task_handle) != eSuspended) {
            allTasksSuspended = false;
          }
          // Check if imu_reading_task_handle is not suspended
          if (imu_reading_task_handle == NULL) {
          } else if (eTaskGetState(imu_reading_task_handle) != eSuspended) {
            allTasksSuspended = false;
          }
          // Check if bme_reading_task_handle is not suspended
          if (bme_reading_task_handle == NULL) {
          } else if (eTaskGetState(bme_reading_task_handle) != eSuspended) {
            allTasksSuspended = false;
          }
          // Check if esp_stats_task_handle is not suspended
          if (esp_stats_task_handle == NULL) {
          } else if (eTaskGetState(esp_stats_task_handle) != eSuspended) {
            allTasksSuspended = false;
          }

          if (allTasksSuspended) {
            break;
          }

          Serial.println("Waiting for tasks to be finished");
          vTaskDelay(pdMS_TO_TICKS(2000));
        }

        //Verifies how much time remaining to start
        long remaining_time_vibration =vibration_timer - millis();
        long remaining_time_bme = bme_timer - millis();
        long remaining_time_gps = gps_timer - millis();
        long remaining_time_mqtt = mqtt_timer - millis();
        long remaining_time_espstats = esp_stats_timer - millis();


        //Configuration of the Wake-on-motion interrupt
        //vTaskDelay because in the first moments the pin become HIGH several Times
        Serial.println("Sleeping now");
        imu_config_sleepmode();
        vTaskDelay(pdMS_TO_TICKS(5000));

        // Configure the wake-up source
        esp_sleep_enable_ext0_wakeup(GPIO_NUM_26, 1);      // Wake up on HIGH signal
        gpio_set_direction(GPIO_NUM_26, GPIO_MODE_INPUT);  // Configuring the GPIO as input
        gpio_pullup_en(GPIO_NUM_26);                       //enabling internal pull-up

        // Enter deep sleep
        esp_light_sleep_start();

        Serial.println("Waking Up!");
        interruptFlag_movement = true;  //Avoid entering immediately again
        order_to_sleep = false;

        vTaskDelay(pdMS_TO_TICKS(100));
        imu_config_accelerometer();

        vTaskDelay(pdMS_TO_TICKS(2000));

        vibration_timer = millis() + remaining_time_vibration;
        bme_timer = millis() + remaining_time_bme;
        gps_timer = millis() + remaining_time_gps;
        mqtt_timer = millis() + remaining_time_mqtt;
        esp_stats_timer = millis() + remaining_time_espstats;
      }

    } else {
      sleepmode_timer = millis() + interval_to_sleep_mode;  // Reset the start time if the imu_reading_task indicates movement
      Serial.println("Resetting the timer to sleep mode");
      interruptFlag_movement = false;  //Resetting the Flag
    }



    vTaskDelay(pdMS_TO_TICKS(200));

    if (imu_reading_task_handle == NULL) {
      xTaskCreatePinnedToCore(imu_reading_task, "Read IMU Values", 5000, NULL, 10, &imu_reading_task_handle, 0);
    } else if (eTaskGetState(imu_reading_task_handle) == eSuspended) {
      vTaskResume(imu_reading_task_handle);
    } else if (eTaskGetState(imu_reading_task_handle) == eDeleted) {
      xTaskCreatePinnedToCore(imu_reading_task, "Read IMU Values", 5000, NULL, 10, &imu_reading_task_handle, 0);
    }

    vTaskDelay(pdMS_TO_TICKS(200));

    if (millis() >= vibration_timer && vibration_mode == true) {
      if (vibration_processing_task_handle == NULL) {
        xTaskCreatePinnedToCore(vibration_processing_task, "Processing Vibration Values", 30000, NULL, 4, &vibration_processing_task_handle, 1);
      } else if (eTaskGetState(vibration_processing_task_handle) == eSuspended) {
        vTaskResume(vibration_processing_task_handle);
      }
      vibration_timer = millis() + vibration_interval_timer;
    }


    if (millis() >= bme_timer && bme_mode == true) {
      if (bme_reading_task_handle == NULL) {
        xTaskCreatePinnedToCore(bme_reading_task, "Read BME Values", 5000, NULL, 10, &bme_reading_task_handle, 1);
      } else if (eTaskGetState(bme_reading_task_handle) == eSuspended) {
        vTaskResume(bme_reading_task_handle);
      } else if (eTaskGetState(bme_reading_task_handle) == eDeleted) {
        xTaskCreatePinnedToCore(bme_reading_task, "Read IMU Values", 5000, NULL, 10, &bme_reading_task_handle, 0);
      }
      bme_timer = millis() + bme_interval_timer;
    }

    vTaskDelay(pdMS_TO_TICKS(200));

    if (sd_communication_task_handle == NULL) {
      xTaskCreatePinnedToCore(sd_communication_task, "Saving Values on the SD Card", 8000, NULL, 10, &sd_communication_task_handle, 1);
    } else if (eTaskGetState(sd_communication_task_handle) == eSuspended && ((uxQueueMessagesWaiting(bme_data_queue) >= 3) || (uxQueueMessagesWaiting(impact_data_queue) >= 50) || (uxQueueMessagesWaiting(vibration_data_queue) >= 200))) {
      vTaskResume(sd_communication_task_handle);
    }

    vTaskDelay(pdMS_TO_TICKS(200));

    if (millis() >= mqtt_timer && mqtt_mode == true) {
      if (mqtt_communication_task_handle == NULL) {
        xTaskCreatePinnedToCore(mqtt_communication_task, "Send the values from the microSD to MQTT", 12000, NULL, 10, &mqtt_communication_task_handle, 1);
      } else if ((eTaskGetState(mqtt_communication_task_handle) == eSuspended)) {
        vTaskResume(mqtt_communication_task_handle);
      }
      mqtt_timer = millis() + mqtt_interval_timer;
    }

    vTaskDelay(pdMS_TO_TICKS(200));

    if (millis() >= gps_timer && gps_mode == true) {
      if (gps_manager_task_handle == NULL) {
        xTaskCreatePinnedToCore(gps_manager_task, "GPS Manager", 4000, NULL, 4, &gps_manager_task_handle, 1);
      } else if ((eTaskGetState(gps_manager_task_handle) == eSuspended)) {
        vTaskResume(gps_manager_task_handle);
      }
      gps_timer = millis() + gps_interval_timer;
    }

    vTaskDelay(pdMS_TO_TICKS(200));

    if (millis() >= esp_stats_timer && esp_stats_mode == true) {
      if (esp_stats_task_handle == NULL) {
        xTaskCreatePinnedToCore(esp_stats_task, "ESP Stats Recorder", 3000, NULL, 1, &esp_stats_task_handle, 1);
      } else if ((eTaskGetState(esp_stats_task_handle) == eSuspended)) {
        vTaskResume(esp_stats_task_handle);
      } else if ((eTaskGetState(esp_stats_task_handle) == eDeleted)) {
        xTaskCreatePinnedToCore(esp_stats_task, "ESP Stats Recorder", 3000, NULL, 1, &esp_stats_task_handle, 1);
      }
      esp_stats_timer = millis() + esp_stats_interval_timer;
    }

    //Debugging Timers
    Serial.println("-----------------------------------------------------------");
    if (vibration_mode == true) {
      Serial.print("Remaining Time to start vibrations monitoring: ");
      Serial.println((vibration_timer - millis()) / 1000);
    } else {
      Serial.println("vibration_mode deactivated.");
    }

    if (bme_mode == true) {
      Serial.print("Remaining Time to start bme: ");
      Serial.println((bme_timer - millis()) / 1000);
    } else {
      Serial.println("bme_mode deactivated.");
    }
    if (gps_mode == true) {
      Serial.print("Remaining Time to start gps: ");
      Serial.println((gps_timer - millis()) / 1000);
    } else {
      Serial.println("gps_mode deactivated.");
    }
    if (mqtt_mode == true) {
      Serial.print("Remaining Time to start mqtt: ");
      Serial.println((mqtt_timer - millis()) / 1000);
    } else {
      Serial.println("mqtt_mode deactivated.");
    }
    if (esp_stats_mode == true) {
      Serial.print("Remaining Time to start esp_stats: ");
      Serial.println((esp_stats_timer - millis()) / 1000);
    } else {
      Serial.println("esp_stats deactivated.");
    }
    Serial.println("-----------------------------------------------------------");


    //If the pin27 button pressed more than 3 seconds, the microcontroller turns off
    if (order_to_turn_off == true) {
      log(INFO, "esp-manager-task", "Turning off the Device Procedure");

      turn_off_procedure();

      Serial.println("Turning OFF!");
      esp_sleep_enable_ext0_wakeup(GPIO_NUM_27, LOW);
      esp_deep_sleep_start();
    }

    vTaskDelay(pdMS_TO_TICKS(5000));
  }
}

//%%%%%%%%%%%%%%%%%%%%%%%%%%%%%%%%%%%%%%%%%%%%%% CORE 0 %%%%%%%%%%%%%%%%%%%%%%%%%%%%%%%%%%%%%%%%%%%%%%%%%%%

///////////////////////////////////////////////////////////////////////////
///////////////////////////////////////////////////////////////////////////
//Function: Read IMU Values and Impact Recognisiton Task

/*
This task monitors accelerometer data in an infinite loop and will detect impacts above a threshold.
It will take samples for the vibration processing task.
It uses a semaphore, the i2cSemaphore to ensure that it is the only task using the I2C bus. 
*/
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
void loop() {}

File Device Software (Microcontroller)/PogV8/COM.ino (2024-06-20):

/////////////////////////////////////////////////////////////////////
/////////////////////   I2C FUNCTIONS   /////////////////////////////

//Function to write a value in a register adress of a slave device by using I2C communication.
void write_I2C(int address, int registerAddress, int value) {
  Wire.beginTransmission(address);  // Start the transmission
  Wire.write(registerAddress);      // write the register adress
  Wire.write(value);                // Write the value
  Wire.endTransmission(true);       // End Transmission
}

//Function to read a value in a register adress of a slave device by using I2C communication.
void read_I2C(int address, int registerAddress) {
  // Read XOUT_H from the IMU
  Wire.beginTransmission(address);
  Wire.write(registerAddress);  // starting with register 0x3B (ACCEL_XOUT_H)
  Wire.endTransmission(false);
  Wire.requestFrom(address, 1, true);  // request a total of 6 registers
  int16_t value = Wire.read();
  Wire.endTransmission(true);

  //For debugging
  Serial.print("Register Address: ");
  Serial.println(registerAddress, HEX);
  Serial.print("Value: ");
  Serial.println(value, BIN);
}

/////////////////////////////////////////////////////////////////////
///////////   GSM COMMUNICATION FUNCTIONS (A9G)  ////////////////////

//Function to configure the A9G and the gsm network

void COM_Config(String task) {

  String receivedMessage = "";
  int startTime = 0;

  //INITIATES THE A9G
  log(INFO, task, "Initiating the A9G Config doing RST");

  startTime = millis();
  SerialPortA9G.println("AT+RST=1");
  /*Expecting this:
  Init... +CREG: 2 +CTZV:18/03/30,06:59:43,+08 +CREG: 1 +CTZV:18/03/30,06:59:44,+08 OK A9/A9G V02.00.20180327RC Ai_Thinker_Co.LTD READY*/

  while ((millis() - startTime) < 60000) {
    String receivedMessage = COM_Read_A9G();

    if (receivedMessage.indexOf("+CTZV:") != -1) {
      //+CTZV:18/03/30,06:59:44,+08

      //Dividing the string to only the date and hour
      int startIndex = receivedMessage.indexOf("+CTZV:");
      int endIndex = startIndex + 27;  // Length of "+CTZV:18/03/30,06:59:44,+08"
      String receivedMessage_Time = receivedMessage.substring(startIndex, endIndex);

      /*For debugging:
      Serial.println("year: " + receivedMessage_Time.substring(6, 8));
      Serial.println("month: " + receivedMessage_Time.substring(9, 11));
      Serial.println("day: " + receivedMessage_Time.substring(12, 14));

      Serial.println("hour: " + receivedMessage_Time.substring(15, 17));
      Serial.println("minutes: " + receivedMessage_Time.substring(18, 20));
      Serial.println("seconds: " + receivedMessage_Time.substring(21, 23));*/

      //Defining the internal real-time clock
      rtc.setTime(receivedMessage_Time.substring(21, 23).toInt(),
                  receivedMessage_Time.substring(18, 20).toInt(),
                  receivedMessage_Time.substring(15, 17).toInt(),
                  receivedMessage_Time.substring(12, 14).toInt(),
                  receivedMessage_Time.substring(9, 11).toInt(),
                  (receivedMessage_Time.substring(6, 8).toInt() + 2000));

      Serial.println("Rtc is synchronized: " + rtc.getDateTime(true));
    }

    if (receivedMessage.indexOf("READY") != -1) {
      log(INFO, task, "A9G READY for receive AT Commands!");
      break;  // Exit the loop if "OK" is found
    }
    delay(100);
  }
  if ((millis() - startTime) >= 30000) {
    log(ERROR, task, "AT+RST Timeout");
  }

  vTaskDelay(pdMS_TO_TICKS(1000));
}

///////////////////////    A9G Network Config   /////////////////////////////////////
// Main function to configure the network
bool COM_Config_Network() {

  SerialPortA9G.println("AT+CGATT=1");
  if (!check_response_A9G(5000, "OK")) {
    log(ERROR, "mqtt-communication-task", "Internet Permissions Denied!");
    return false;
  }

  log(INFO, "mqtt-communication-task", "Internet Permissions OK!");
  vTaskDelay(pdMS_TO_TICKS(1000));

  SerialPortA9G.println("AT+CGDCONT=1,\"IP\",\"" + apn + "\"");
  if (!check_response_A9G(5000, "OK")) {
    log(ERROR, "mqtt-communication-task", "Configuration of the APN Server not succeeded!");
    return false;
  }

  /*SerialPortA9G.println("AT+CGDCONT=1,\"IP\",\"net2.vodafone.pt\"");
  if (!check_response_A9G(5000, "OK")) {
    log(ERROR, "mqtt_communication_task", "Configuration of the APN Server not successed!");
    return false;
  }*/

  log(INFO, "mqtt-communication-task", "Configuration of the APN Server successed!");
  vTaskDelay(pdMS_TO_TICKS(1000));

  SerialPortA9G.println("AT+CGACT=1,1");
  if (!check_response_A9G(5000, "OK")) {
    log(ERROR, "mqtt-communication-task", "Connection to the APN Server not successed!");
    return false;
  }

  log(INFO, "mqtt-communication-task", "Connection to the APN Server successed!");
  vTaskDelay(pdMS_TO_TICKS(1000));

  // Configuration of the MQTT Server
  SerialPortA9G.println("AT+MQTTCONN=\"" + adress_broker_mqtt + "\"," + port_broker_mqtt + ",\"" + data_logger_id + "\",120,0");
  if (!check_response_A9G(10000, "OK")) {
    log(ERROR, "mqtt-communication-task", "Connection not sucessfully with the MQTT Server!");
    return false;
  }

  log(INFO, "mqtt-communication-task", "MQTT Server Connected!");
  vTaskDelay(pdMS_TO_TICKS(1000));

  return true;
}


/////////////////// Function to send a MQTT Setence ///////////////////////////

bool COM_send_MQTT(String data_source, String data) {
  String MQTT_setence = "%" + data_logger_id + "%";
  MQTT_setence += data_source + ",";
  MQTT_setence += data;

  Serial.println(MQTT_setence);

  SerialPortA9G.println("AT+MQTTPUB=\"" + data_source + "\",\"" + MQTT_setence + "\",0,0,0");
  if (!check_response_A9G(20000, "OK")) {
    Serial.println("Failed to send MQTT setence");
    return false;
  }

  vTaskDelay(pdMS_TO_TICKS(500));

  /*/ Turning off the MQTT Server
  SerialPortA9G.println("AT+MQTTDISCONN");
  if (!check_response_A9G(10000,"OK")) {
    Serial.println("Failed to disconnect from MQTT Server");
    return false;
  }*/

  return true;
}

///////////////////////////////////////////////////////////////////////////////

//Function to read the Serial Port from A9G
String COM_Read_A9G() {
  if (SerialPortA9G.available()) {
    String message_read = "";
    while (SerialPortA9G.available()) {
      char char_read = SerialPortA9G.read();  // Read one character from the serial port
      message_read += char_read;              //Construction of the message
    }
    return message_read;
  }
}

// Function to check for a specific response
bool check_response_A9G(int timeout, String expectedResponse) {
  int startTime = millis();
  while ((millis() - startTime) < timeout) {
    String receivedMessage = COM_Read_A9G();
    if (receivedMessage.indexOf(expectedResponse) != -1) {
      return true;
    }
  }
  return false;
}

///////////////// SD TO MQTT Function //////////////////////////////
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

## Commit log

2024-05-24 Add the humidity test
    [bme_data_test_humidity.csv]
2024-06-03 update tests
    [Impact Validation 2_2024-05-25_19-56.xlsx, Teste1_aspion.xlsx, Teste1_datalogger.xlsx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]
2024-06-03 Update with hardware program and tests
    [Energy Consumption Table.xlsx, route1.csv, route2.csv]
2024-06-03 Add django webframework
    [config.txt, trip_config.txt]
2024-06-21 Add temperature Validation Test
    [bme_data_teste_forno.csv]
